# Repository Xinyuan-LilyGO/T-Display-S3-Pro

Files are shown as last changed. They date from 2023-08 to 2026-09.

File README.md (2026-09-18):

<div align="center" markdown="1">
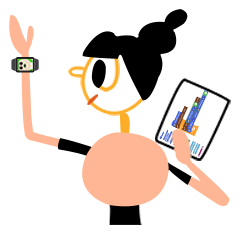
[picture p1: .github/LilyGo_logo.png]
LilyGo logo
  
</div>

<h1 align = "center">🌟 T-Display-S3-Pro 🌟</h1>



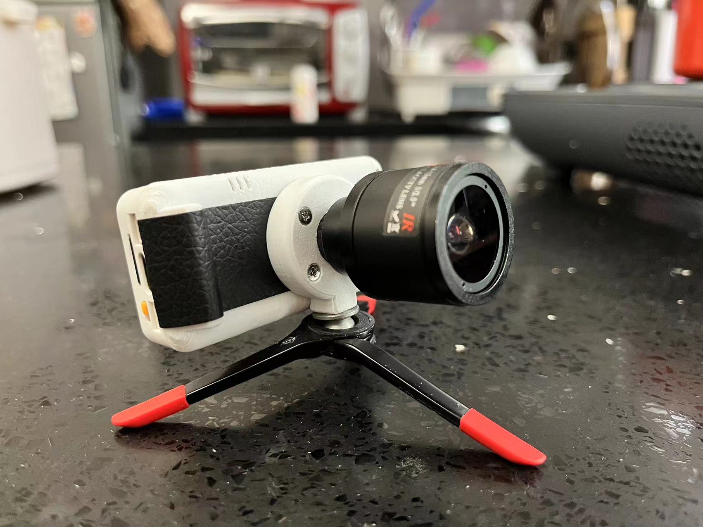
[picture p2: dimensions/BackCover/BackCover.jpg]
BackCover


---

## 📖 Table of Contents

- [📖 Table of Contents](#-table-of-contents)
- [📋 Product](#-product)
- [🚀 Quick Start](#-quick-start)
  - [PlatformIO Quick Start (Recommended)](#platformio-quick-start-recommended)
  - [Arduino IDE Quick Start](#arduino-ide-quick-start)
- [💾 Flash Factory Firmware](#-flash-factory-firmware)
- [🔧 Hardware Description](#-hardware-description)
  - [📍 Pins Map](#-pins-map)
  - [✨ Display Features](#-display-features)
  - [🧑🏼‍🔧 I2C Devices Address](#-i2c-devices-address)
  - [⚡ Electrical Parameters](#-electrical-parameters)
  - [💡 LED](#-led)
  - [🔌 QWIIC Connector](#-qwiic-connector)
  - [⏺︎ Button](#︎-button)
  - [📴 Switch](#-switch)
- [📚 Examples](#-examples)
  - [ESP32 Basic Examples](#esp32-basic-examples)
- [📄 Datasheet](#-datasheet)
- [📐 Case \& Dimensions](#-case--dimensions)
- [❓ FAQ](#-faq)
  - [1. Upload port not found?](#1-upload-port-not-found)
  - [2. Manual upload didn't work?](#2-manual-upload-didnt-work)
  - [3. OTG external power not working?](#3-otg-external-power-not-working)
  - [4. What does the physical switch do?](#4-what-does-the-physical-switch-do)
  - [5. LED flashing when battery not connected?](#5-led-flashing-when-battery-not-connected)
  - [6. Device suddenly shuts down?](#6-device-suddenly-shuts-down)
- [📦 Dependencies](#-dependencies)

---

## 📋 Product

| Product (PinMap) | SOC | Flash | PSRAM | Resolution | LTR-553ALS |
| --- | --- | ----- | --- | --- | --- |
| [T-Display-S3-Pro][1] | ESP32-S3R8 | 16MB  | 8MB(OPI) | 222x480 | ✅ |
| [T-Display-S3-Pro External][1]  | ESP32-S3R8 | 16MB  | 8MB(OPI) | 222x480 | X |
| [T-Display-S3-Pro-MVSRBoard][1] | - | - | - | - | |
| [T-Display-S3-Pro-MVSRLora][1]  | - | - | - | - | |

[1]: https://www.lilygo.cc/products/t-display-s3-pro
[2]: https://lilygo.cc/products/t-display-s3-pro-external

> **Note:**  The T-Display-S3-Pro supports multiple camera models, depending on the model purchased.
> The LTR-553ALS ambient light sensor is included only on the T-Display-S3-Pro; the T-Display-S3-Pro External does not feature this sensor.
>

---

## 🚀 Quick Start

### PlatformIO Quick Start (Recommended)

1. Install [Visual Studio Code](https://code.visualstudio.com/) and [Python](https://www.python.org/)
2. Search for the `PlatformIO` plugin in Visual Studio Code extension marketplace and install it
3. Restart Visual Studio Code after installation
4. Open `File` → `Open Folder` → select the `T-Display-S3-Pro` directory
5. Wait for third-party library dependencies to install automatically
6. Open `platformio.ini` and uncomment the desired `default_envs = xxxx` line (only one should be active)
7. Click the (✔) icon in the bottom-left corner to compile
8. Connect the board via USB, click (→) to upload firmware
9. Click the (plug symbol) to monitor serial output
10. If upload fails or the USB device keeps flashing, refer to the **FAQ** section below

### Arduino IDE Quick Start

> **Note:** PlatformIO is recommended for a smoother development experience.

1. Install [Arduino IDE](https://www.arduino.cc/en/software)
2. Add the ESP32 board URL in Arduino Preferences → `Additional boards manager URLs`:
   ```
   https://raw.githubusercontent.com/espressif/arduino-esp32/gh-pages/package_esp32_index.json
   ```
   > **Important:** Use Arduino ESP32 core version **2.0.14** or lower. Versions above 2.0.14 may have compatibility issues with TFT_eSPI. See [TFT_eSPI Issue #3329](https://github.com/Bodmer/TFT_eSPI/issues/3329)

3. Copy all folders from the [lib folder](./lib/) to your Arduino libraries directory (e.g., `C:\Users\YourName\Documents\Arduino\libraries`)
4. Configure the board settings as follows:

   | Setting          | Value                               |
   | ---------------- | ----------------------------------- |
   | Board            | **ESP32S3 Dev Module**              |
   | Port             | Your port                           |
   | USB CDC On Boot  | Enable                              |
   | CPU Frequency    | 240MHz (WiFi)                       |
   | Flash Mode       | QIO 80MHz                           |
   | Flash Size       | **16MB (128Mb)**                    |
   | Partition Scheme | **16M Flash (3MB APP/9.9MB FATFS)** |
   | PSRAM            | **QSPI PSRAM**                      |
   | Upload Speed     | 921600                              |

5. Open `T-Display-S3-Pro` → `examples` → select an example → open the `.ino` file
6. Select the correct Port and click Upload

> **Troubleshooting:** If upload fails or the USB device keeps flashing, refer to the **FAQ** section below.

---

## 💾 Flash Factory Firmware

If you need to restore the factory firmware or flash the UnitTest firmware for hardware testing, please refer to the [Firmware Flashing Guide](./firmware/README.MD).

---

## 🔧 Hardware Description

### 📍 Pins Map

| Name | GPIO | Note |
| --- | --- | --- |
| SDA | 5 | |
| SCL | 6 | |
| SPI MISO | 8 | |
| SPI MOSI | 17 | |
| SPI SCLK | 18 | |
| DISPLAY CS | 39 | |
| DISPLAY MISO/MOSI/SCLK | 8/17/18 | Share SPI Bus |
| BACKLIGHT PIN | 48 | 16-level dimming |
| SD CS | 14 | |
| SD MISO/MOSI/SCLK | 8/17/18 | Share SPI Bus |
| TOUCH RST | 13 | |
| TOUCH SDA/SCL | 5/6 | Share I2C Bus |
| BUTTON 1 (BOOT) | 0 | User button, also used for download mode |
| BUTTON 2 | 12 | User button |
| BUTTON 3 | 16 | User button |
| On board LED (Green) | 38 | |
| CAMERA RST | - | NC |
| CAMERA SDA/SCL | 5/6 | Share I2C Bus |
| CAMERA VSYNC | 7 | |
| CAMERA POWER DOWN | 46 | |
| CAMERA HREF | 15 | |
| CAMERA XCLK | 4 | |
| CAMERA PCLK | 2 | |
| CAMERA Y2-Y9 | 45,41,40,42,1,3,10,4 | |
| CAMERA LED | 38 | Share Onboard LED |
| CAMERA Default frequency | 20MHz | |

> **Note:** V1.0 uses PWM for backlight adjustment, while V1.1 uses constant current drive. See [AdjustBacklight example](./examples/AdjustBacklight/AdjustBacklight.ino) for details.

### ✨ Display Features

| Feature | Value |
| --- | --- |
| Resolution | 480 × 222 |
| Display Size | 2.33 Inch |
| Luminance | 450 cd/m² |
| Driver IC | ST7796U (SPI) |
| Contrast Ratio | 1000:1 |
| Color Gamut | 70% |
| PPI | 221 |
| Display Colors | 262K |
| View Direction | All (IPS) |
| Operating Temperature | -20 ~ 70°C |

### 🧑🏼‍🔧 I2C Devices Address

| Device | 7-Bit Address | Shared Bus |
| --- | --- | --- |
| [PowerManage SY6970][2] | 0x6A | ✅ |
| [Optical Sensor LTR-553ALS][3]  | 0x23 | ✅ |
| Capacitive Touchscreen CST226SE | 0x5A | ✅ |

[2]: https://www.visvie.com/static/upload/file/20220916/1663318546578220.pdf
[3]: https://optoelectronics.liteon.com/upload/download/DS86-2014-0007/LTR-553ALS-01_DS_V1.pdf

### ⚡ Electrical Parameters

| Feature | Details |
| --- | --- |
| 🔗 USB-C Input Voltage  | 3.9V - 6V |
| 🔗 USB-C Output Voltage | 4.55 - 5.55V |
| ⚡ USB-C Output Current | 0.5 - 1A |
| ⚡ Charge Current | 0 - 5056mA (Programmable) |
| 🔋 Battery Voltage | 3840 ~ 4608mV (Programmable) |
| 🔋 Battery Capacity | 3800mV / 470mAh |
| 🔋 Battery Connector | [ACHL Connector 1.2mm][4] |
| 🔋 Charge Temperature | 0 ~ 60°C |

[4]: https://www.jst.com/zh/products/crimp-style-connectors-wire-to-board-type/achl-connector/

> [!IMPORTANT]
> - ⚠️ Recommended charging current: **< 200mA**
> - ⚠️ Charging current should not exceed half of battery capacity
> - The T-Display-S3-Pro uses the SY6970 power path switching chip. To maintain stable power when battery is disconnected, charging must be disabled. See [PMU_Example](https://github.com/Xinyuan-LilyGO/T-Display-S3-Pro/blob/c267d7463609e1f6c62e74455ac5048c9ae93bc3/examples/PMU_Example/PMU_Example.ino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) for details.

### 💡 LED

| LED | GPIO | Note |
| --- | ---- | --- |
| Green LED | 38 | Shared with camera fill light on camera shield models |
| Red LED | - | Charger status indicator |

> **Note:** The red LED flashes when no battery is connected. Disable via `PMU.disableStatLed();` - see [FAQ](#faq).

### 🔌 QWIIC Connector

| Connector | GPIO | Description |
| --- | --- | --- |
| LEFT | 44, 43, 3V3, GND | UART / I2C / GPIO |
| RIGHT | SCL(6), SDA(5), 3V3, GND | I2C only |

> **Note:** Screen should be facing you to determine direction.

### ⏺︎ Button

| LED | GPIO | Note |
| --- | --- | --- |
| LEFT TOP | RESET | Reset Device |
| LEFT BOTTOM  | BOOT (GPIO0) | User button, also used for download mode |
| RIGHT TOP | 12 | User button |
| RIGHT BOTTOM | 16 | User button |

> **Note:** Screen should be facing you to determine direction.

### 📴 Switch

* The power switch is only effective when the battery is connected; disconnect the battery from the motherboard.

---

## 📚 Examples

```txt
T-Display-S3-Pro examples
├── examples/Arduino_GFX_HelloWorld      # Arduino_GFX getting started
├── examples/Arduino_GFX_LvglBenchmark   # Arduino_GFX + LVGL benchmark
├── examples/Arduino_GFX_PDQgraphicstest  # Arduino_GFX graphics test
├── examples/CameraShield                 # Camera example
├── examples/CapacitiveTouch              # Capacitive touch example
├── examples/LTR553ALS_Sensor             # Light & proximity sensor
├── examples/TFT_eSPI_Simple             # TFT_eSPI example
├── examples/USB_HID_Example              # USB Host HID & OTG
├── examples/UnitTest                     # Hardware unit testing
├── examples/PMU_Example                  # Power management & battery info
├── examples/AdjustBacklight              # Backlight adjustment
├── examples/Cellphone                    # Camera & photo album (SD required)
└── examples/factory                     # Factory testing
```

> [!CAUTION]
> When using `examples/Cellphone`, do not block the top of the "S3-Pro" screen area. Blocking this area will cause the screen to sleep.

Expansion board examples:

- [T-Display-S3-Pro-MVSRBoard](https://github.com/Xinyuan-LilyGO/T-Display-S3-Pro-MVSRBoard)
- [T-Display-S3-Pro-MVSRLora](https://github.com/Xinyuan-LilyGO/T-Display-S3-Pro-MVSRLora)

### ESP32 Basic Examples

- [BLE Examples](https://github.com/espressif/arduino-esp32/tree/master/libraries/BLE)
- [WiFi Examples](https://github.com/espressif/arduino-esp32/tree/master/libraries/WiFi)
- [SPIFFS Examples](https://github.com/espressif/arduino-esp32/tree/master/libraries/SPIFFS)
- [FFat Examples](https://github.com/espressif/arduino-esp32/tree/master/libraries/FFat)
- More examples available at [arduino-esp32-libraries](https://github.com/espressif/arduino-esp32/tree/master/libraries)

---

## 📄 Datasheet

- [Camera-Shield](./schematic/Camer-Shield.pdf)
- [T-Display-S3-Pro](./schematic/T-Display-Pro.pdf)
- [T-BHI260](./schematic/T-BHI260_V1.1.pdf)
- [T-Display-S3-Pro-MVSRBoard_V1.0_20240913](./schematic/T-Display-S3-Pro-MVSRBoard_V1.0_20240913.pdf)
- [T-Display-S3-Pro-MVSRBoard_V1.0_20241109](./schematic/T-Display-S3-Pro-MVSRBoard_V1.0_20241109.pdf)

## 📐 Case & Dimensions

- 🔓 Cool back cover design by @moononournation - [Design files](./dimensions/BackCover/)
- [T-Display-Pro PCB](./dimensions/T-Display-Pro-PCB.DWG)
- [T-Display-Pro-Vice-Shield](./dimensions/T-Display-Pro-Vice-Shield.dxf)
- [T-Display-Pro-Vice-Shield Gerber](./dimensions/T-Display-Pro-Vice-Shield%20Gerber%2023-11-23.zip)
- [T-BHI260.kicad_mod](./schematic/kicad_sensor.pretty/T-BHI260.kicad_mod)
- [T-CIM29048.kicad_mod](./schematic/kicad_sensor.pretty/T-CIM29048.kicad_mod)

---

## ❓ FAQ

### 1. Upload port not found?

The board uses USB as the JTAG upload port. Ensure `USB_CDC_ON_BOOT` is enabled.

If the port does not appear or USB is used for other functions, enter upload mode manually:

1. Connect the board via USB cable
2. Press and hold the **BOOT** button
3. While holding BOOT, press **RST**
4. Release RST
5. Release BOOT
6. Retry upload

### 2. Manual upload didn't work?

Try burning the [firmware file](./firmware/README.MD) to verify hardware functionality.

### 3. OTG external power not working?

Enable [PMU OTG](https://github.com/Xinyuan-LilyGO/T-Display-S3-Pro/blob/d7f15b379da2b6f711998315401c02a740a8bfa8/examples/CameraShield/CameraShield.ino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). When USB input is connected and OTG is set to output, the battery will not charge.

### 4. What does the physical switch do?

Setting the switch to **OFF** completely disconnects the battery from the mainboard. Set to **ON** for charging.

### 5. LED flashing when battery not connected?

Use `PMU.disableStatLed();` to disable the indicator. Note this also disables the charging status indicator. To re-enable, call `PMU.enableStatLed();`

### 6. Device suddenly shuts down?

Sudden shutdown only occurs when battery is not connected. Solution: disable SY6970 charging. See [PMU_Example](https://github.com/Xinyuan-LilyGO/T-Display-S3-Pro/blob/c267d7463609e1f6c62e74455ac5048c9ae93bc3/examples/PMU_Example/PMU_Example.ino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).

---

## 📦 Dependencies

| Library | Repository |
| --- | --- |
| XPowersLib | [GitHub](https://github.com/lewisxhe/XPowersLib) |
| SensorLib | [GitHub](https://github.com/lewisxhe/SensorLib) |
| lvgl | [GitHub](https://github.com/lvgl/lvgl) (v8.3.1) |
| TFT_eSPI | [GitHub](https://github.com/Bodmer/TFT_eSPI) |
| TouchLib | [GitHub](https://github.com/mmMicky/TouchLib) |
| Arduino_GFX | [GitHub](https://github.com/moononournation/Arduino_GFX) |
| MPU9250 | [GitHub](https://github.com/hideakitai/MPU9250) |
| MPU6050 | [GitHub](https://github.com/electroniccats/mpu6050) |
| ESP32_USB_Stream | [GitHub](https://github.com/esp-arduino-libs/ESP32_USB_Stream) (v0.0.1) |
| ESP32-audioI2S | [GitHub](https://github.com/schreibfaul1/ESP32-audioI2S) (v3.0.8) |
| JPEGDEC | [GitHub](https://github.com/bitbank2/JPEGDEC) (v1.2.8) |

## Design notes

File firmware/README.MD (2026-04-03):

<div align="center" markdown="1">
  LilyGo logo
</div>

<h1 align = "center">🌟 How to Flash Firmware 🌟</h1>

## Table of Contents

- [Table of Contents](#table-of-contents)
- [Firmware](#firmware)
- [Enter Download Mode](#enter-download-mode)
- [Flash Methods](#flash-methods)
  - [ESP-Launchpad Online](#esp-launchpad-online)
  - [Use ESP Download Tool](#use-esp-download-tool)
  - [Use Web Flasher](#use-web-flasher)
  - [Use Command Line](#use-command-line)
- [Verify Flashing Success](#verify-flashing-success)
  - [Check Boot Log](#check-boot-log)

## Firmware

The difference between V1.0 and V1.1 is that the backlight driver is different. If the wrong firmware is flashed, the backlight may not work correctly.

| Firmware | Description |
| --- | --- |
| Factory_1.x.bin | Default factory-installed desktop firmware |
| UnitTest_V1.x_Release.bin | Firmware for testing hardware, outputting debugging information to Qwiic UART |
| UnitTest_V1.x_Debug.bin | Firmware for testing hardware, output debugging information to USB CDC |
| UnitTest_V1.x_DiscChg_Release.bin | Firmware for testing hardware, disable charge function, outputting debugging information to Qwiic UART |
| UnitTest_V1.x_DiscChg_Debug.bin | Firmware for testing hardware, disable charge function, output debugging information to USB CDC |

## Enter Download Mode

> [!CAUTION]
> Before flashing, you need to know how to put your device into download mode.

1. Connect the board via USB cable
2. Press and hold the **BOOT** button
3. While holding BOOT, press **RST**
4. Release RST
5. Release BOOT
6. Retry upload
7. If the USB port is recognized, the device enters download mode.

## Flash Methods

### ESP-Launchpad Online

- [Esp-launchpad](https://espressif.github.io/esp-launchpad/)

ESP-Launchpad

* Note that after flashing is completed, you need to press RST to reset.

### Use ESP Download Tool

- Download [Flash_download_tool](https://dl.espressif.com/public/flash_download_tool.zip)

web_flasher

* Note that after flashing is completed, you need to press RST to reset.

### Use Web Flasher

- [ESP Web Flasher Online](https://espressif.github.io/esptool-js/)

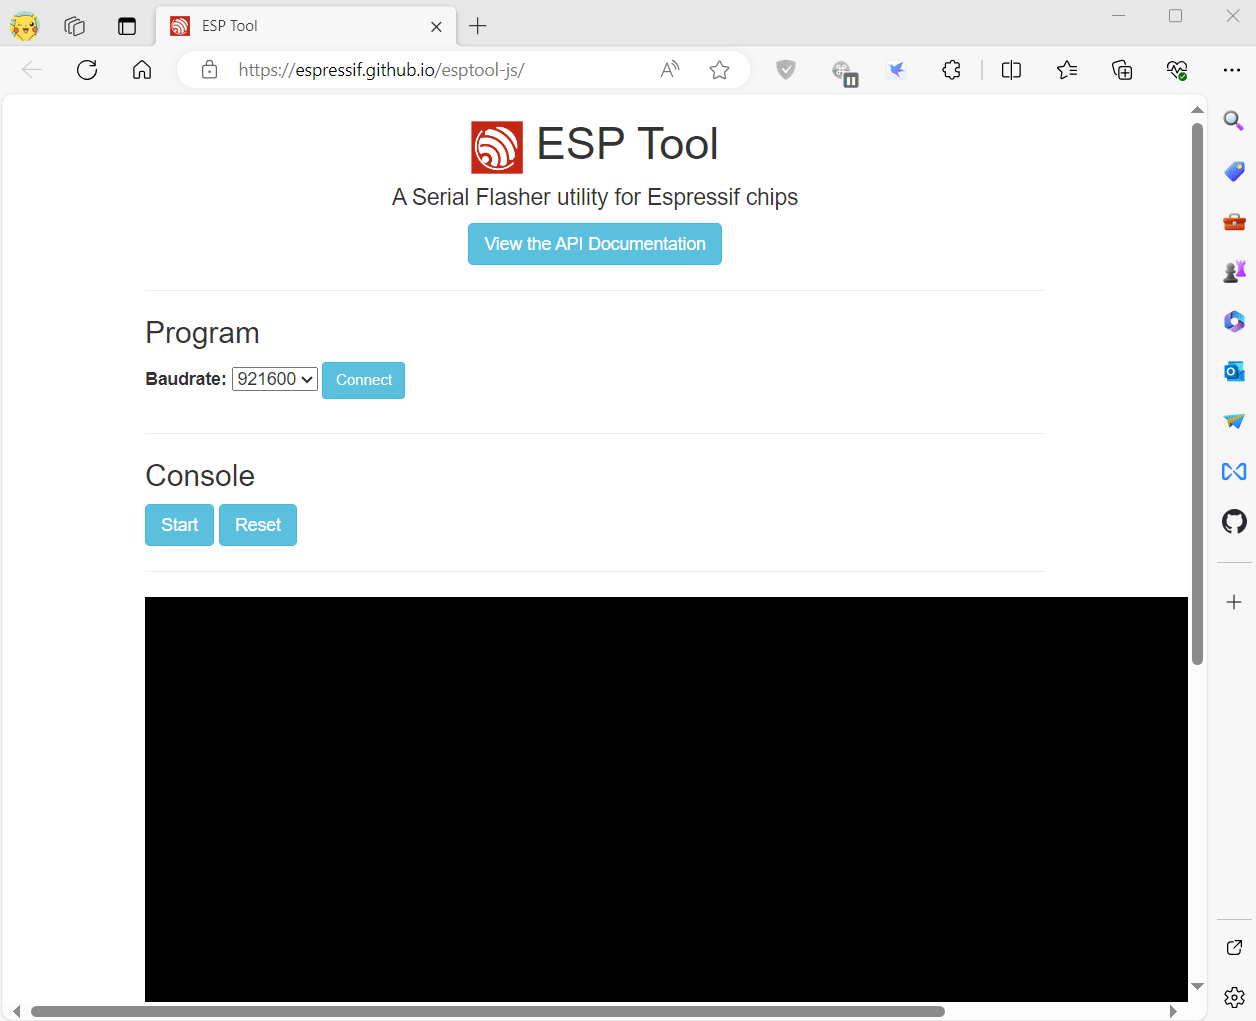
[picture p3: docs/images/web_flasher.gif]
web_flasher


* Note that after flashing is completed, you need to press RST to reset.

### Use Command Line

If prompted to install Developer Tools, do so.

```bash
python3 -m pip install --upgrade pip
python3 -m pip install esptool
```

To launch esptool.py, run:

```bash
python3 -m esptool
```

For ESP32-S3, use the following command to flash:

```bash
esptool --chip esp32s3  --baud 921600 --before default_reset --after hard_reset write_flash -z --flash_mode dio --flash_freq 80m 0x0 firmware.bin
```

## Verify Flashing Success

### Check Boot Log

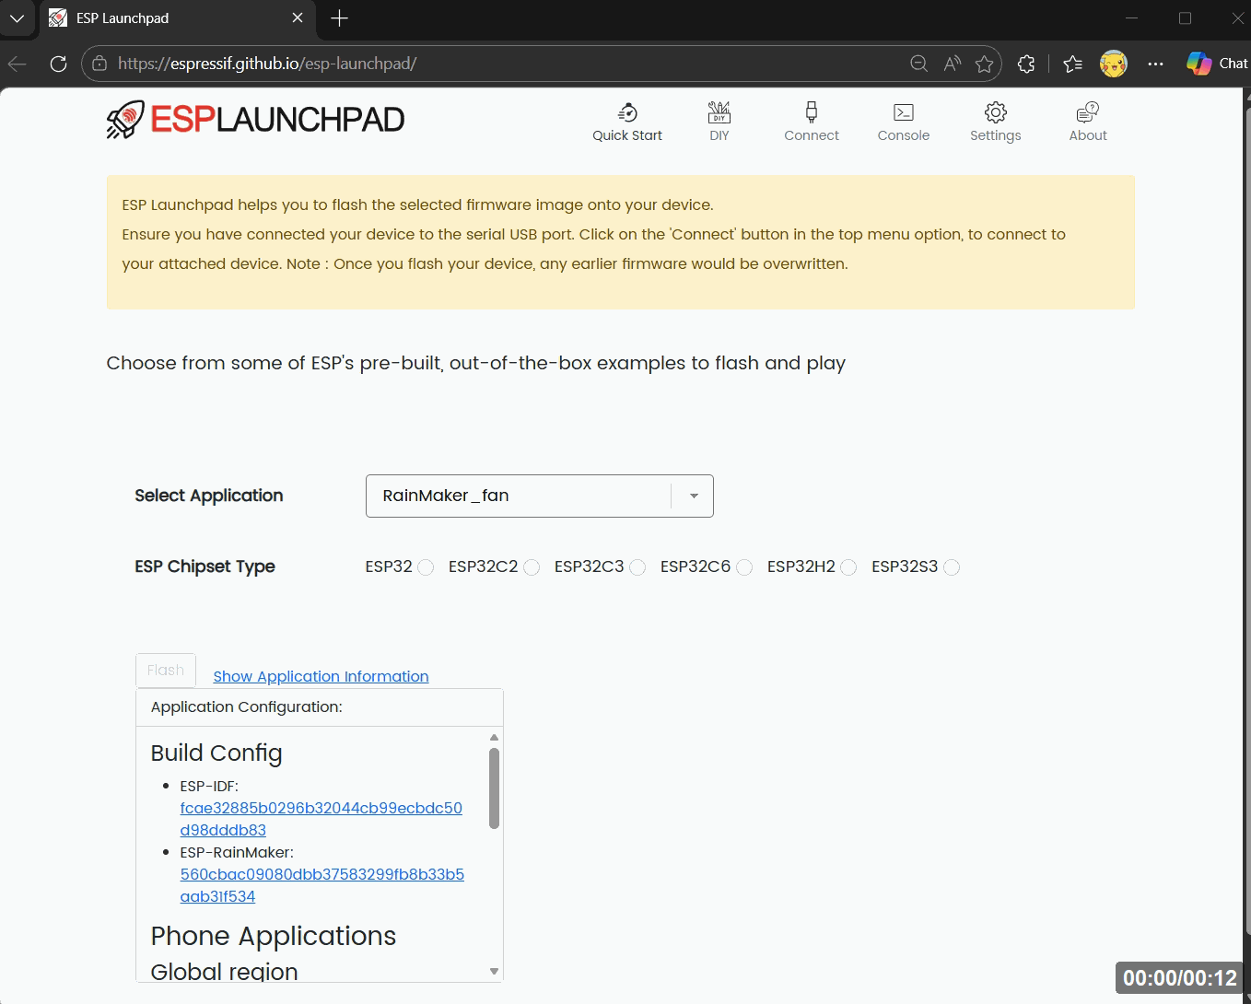
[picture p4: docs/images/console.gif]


* If you can see the device's boot log printed by resetting it serially, and the USB port is recognized, then it has booted normally.
* If the USB port is not recognized and is flashing after uploading, it may be due to an incorrect firmware address. Generally, the write address for LilyGo firmware is 0x00.

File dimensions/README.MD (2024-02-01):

# T-Display-Pro-Vice-Shield

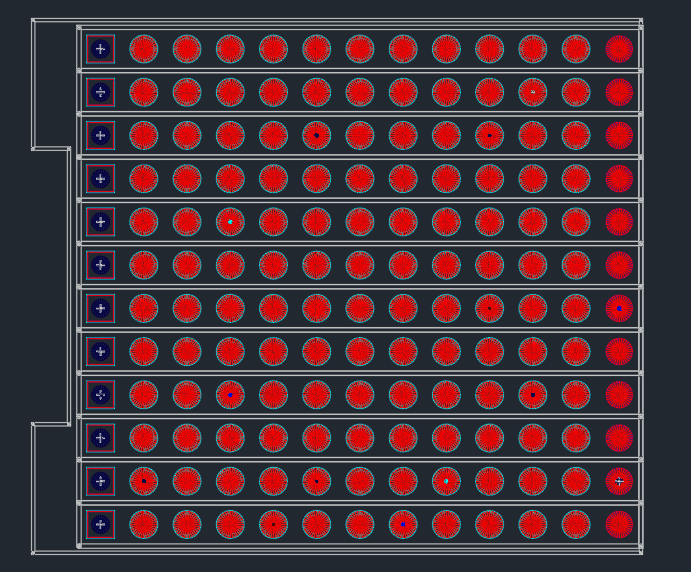
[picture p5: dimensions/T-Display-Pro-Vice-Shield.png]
T-Display-Pro-Vice-Shield


# BackCover 

**Contributed by @moononournation**
 


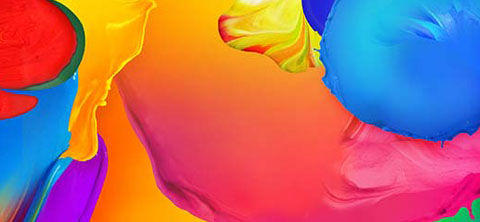
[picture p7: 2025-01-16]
examples/TJpg_Decoder/480x222.jpg

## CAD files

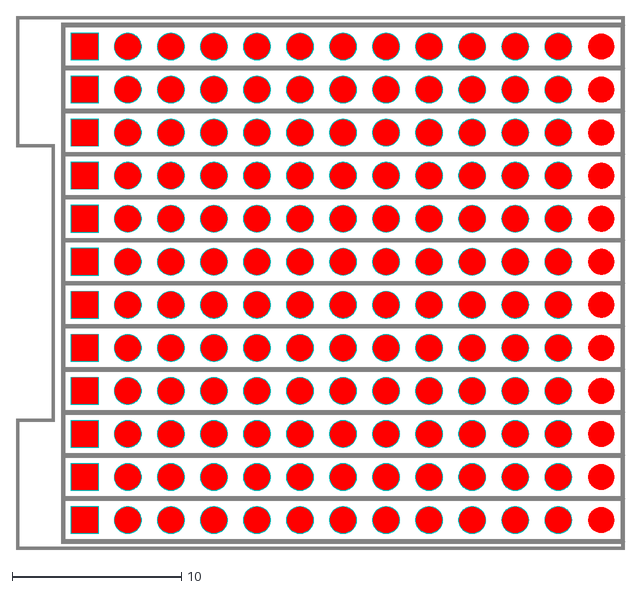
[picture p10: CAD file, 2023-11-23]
dimensions/T-Display-Pro-Vice-Shield.dxf
35.9 x 31.5

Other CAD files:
dimensions/T-Display-Pro-PCB.DWG
dimensions/BackCover/K231-camera-back v6.f3d
dimensions/BackCover/K231-lens-mount v3.f3d

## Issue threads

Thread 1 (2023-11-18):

lib/Arduino_GFX directory is empty so the Arduino_GFX* examples fail to build

esp32beans, 2023-11-18:
Installing "GFX Library for Arduino" by "Moon On Our Nation" version 1.4.0 (latest) using the IDE Library manager fixes the problem. All the Arduino_GFX_* examples work fine now.

lewisxhe, 2023-12-29:
Fixed

Closed 2023-12-29.

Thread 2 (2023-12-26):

Battery information

stutteringp0et, 2023-12-26:
Having been burned by one of your products before, where a replacement battery cannot be purchased - I'd like some information on the battery included with this device.  Specifications so I can determine if a replacement can be sourced when the included battery fails.

lewisxhe, 2023-12-29:
I will add it later, I need to consult

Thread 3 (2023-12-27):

Black Screen

Mcfly46, 2023-12-27:
Hello,
I Have black screen with my device.
I flashed with the factory bin  but no screen. So hardware is broken ?
Thank you.

lewisxhe, 2023-12-29:
Did you follow the instructions?
https://github.com/Xinyuan-LilyGO/T-Display-S3-Pro/tree/master/firmware

jalakoo, 2024-07-11:
I have a similar issue. Regardless of sample app used, after uploading I end up with a blank, black screen.

Using a Mac, so the flash download tool isn't available. Have yet to find an alternate means of flashing the factory.bin to the board.

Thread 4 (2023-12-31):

Touch not working reliable

pixelwave, 2023-12-31:
I have the issue that the touch screen is not working reliable on my T-Display-S3-Pro. The problem is with the factory code as well as my custom code using Arduino GFX + LVGL. When using the "capacity touch" sample code it seems to detect all inputs so it does not really seem like the device itself is broken? I also have a second unit - same behaviour?

https://github.com/Xinyuan-LilyGO/T-Display-S3-Pro/assets/19491804/4728e317-8e50-4639-a78a-a0311a4c3041

https://github.com/Xinyuan-LilyGO/T-Display-S3-Pro/assets/19491804/d52b48f9-dbf8-43fa-9f5b-b6b743c385fd

lewisxhe, 2023-12-31:
First confirm whether the touch is normal, you can write https://github.com/Xinyuan-LilyGO/T-Display-S3-Pro/tree/master/examples/CapacitiveTouch to test.

pixelwave, 2023-12-31:
> First confirm whether the touch is normal, you can write https://github.com/Xinyuan-LilyGO/T-Display-S3-Pro/tree/master/examples/CapacitiveTouch to test.

Did you read my post? That is what I already confirmed „.. when using the "capacity touch" sample code it seems to detect all inputs so it does not really seem like the device itself is broken“.

pixelwave, 2023-12-31:
Still troubleshooting … the issue seems to get worse when using battery instead of usb power?

lewisxhe, 2023-12-31:
When you apply it in your project, have you printed the touch output coordinates and are they normal? Or do you display it on the screen and observe whether the coordinates are the same as the actual touch position?

pixelwave, 2024-01-01:
So I can confirm it has something to do with battery vs usb powered mode.

You can try my sample code yourself (https://github.com/pixelwave/t-display-s3-pro) with the following test setups:

1) Power Switch "OFF", connected and powered from USB port (PC/Laptop)
2) Power Switch "ON" battery powered only

In scenario 1) the touch inputs work reliably and 99% of the time. In Scenario 2) the touch is a hit and miss. Sometimes the buttons work sometimes not.

So in summary I assume a general hardware issue with the board design. I hope this can be resolved in an updated version (I have V1.1) because otherwise the product is quite awesome! But with that flaw currently unusable im battery mode.

Contacting support to find a solution ..

ShallowGreen123, 2024-01-02:
Please tell me how many S3-Pro you bought in total, you can contact the after-sales service to return or replace the goods.

pixelwave, 2024-01-02:
I bought 2 in total already contacted sales (sales@lilygo.cc) and they forwarded it to the orders (orders@lilygo.cc) team. Currently waiting for their feedback. I noticed you are using a different unit? Is it maybe a preproduction or newer unit? Has there been any updates since V1.1? Because both my units show the same behaviour I tend to believe it is more a general hardware design issue?

See below my production (V1.1) device with and without cable:

https://github.com/Xinyuan-LilyGO/T-Display-S3-Pro/assets/19491804/058bc7e9-1d75-4273-9e98-23b69ad9c587

https://github.com/Xinyuan-LilyGO/T-Display-S3-Pro/assets/19491804/4569dcfc-1853-47ad-8aff-7bc7a3949baa

lewisxhe, 2024-01-02:
I know what your problem is. Please change it to the following:
`
build_flags=
        ; -DARDUINO_USB_CDC_ON_BOOT=1
        -UARDUINO_USB_CDC_ON_BOOT
`

If Cdc is turned on, the serial port will block the program from running.

pixelwave, 2024-01-02:
The arguments are as written in the official lilygo sample code.

But I compiled it with the variables like you suggested:
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

No change same behaviour. When in "battery mode" touch screen does NOT work reliably.

lewisxhe, 2024-01-03:
Please note that
`
; -DARDUINO_USB_CDC_ON_BOOT=1
`
has been commented out and
`
 -UARDUINO_USB_CDC_ON_BOOT
`
is enabled

pixelwave, 2024-01-03:
Compiled now like this:

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

Still unchanged behaviour. USB powered = all fine. Battery powered = touch very janky.

lewisxhe, 2024-01-03:
If you can try to enter the binary file I provided, and test whether it is caused by environmental reasons.

The writing method can follow  [here](https://github.com/Xinyuan-LilyGO/LilyGo-Document/blob/master/MacFlashBin.md)

[t-display-s3-pro_0103.zip](https://github.com/Xinyuan-LilyGO/T-Display-S3-Pro/files/13816595/t-display-s3-pro_0103.zip)

pixelwave, 2024-01-03:
Flashed once with esptool and once with thonny. Same faulty behaviour.

pixelwave, 2024-01-03:
Flashing worked both times. I just wanted to try with different tools. Also both times completely erased flash.

The touch problem is still there.

lewisxhe, 2024-01-03:
I have received a message from customer service. I am very curious about what the problem is. Customer service will communicate with you next. I hope to send back these two boards. I want to find out the reason.

pixelwave, 2024-01-03:
Yes me too! Would love to ultimately fix the problem and have working boards. Because the product and paper is great. So I am going to contact with customer support next to send the boards back? I will leave the code on there for you to check ...

pixelwave, 2024-01-08:
... support is not answering anymore? I asked how to return the product. Can you help or contact them?

lewisxhe, 2024-01-08:
Haven't you already contacted customer service?

lewisxhe, 2024-01-08:
Tomorrow I will ask how to deal with it, and I will reply to you here after I get the answer.

pixelwave, 2024-01-08:
Thanks a lot!

lewisxhe, 2024-01-10:
> Thanks a lot!

Did customer service contact you?

pixelwave, 2024-01-10:
Did yesterday - thanks for pinging. But still waiting for their solution on how to ship back the products.

samarkh, 2024-02-25:
My unit also has the same issue, fine on USB power, but bad when self-powered.

pixelwave, 2024-02-25:
After all testing I really think it is a hardware based issue. Maybe just for this specific revision (mine was V1.1). @lewisxhe BTW I am still waiting for the shipping cost refund until I can return the two units for you to test ...

lewisxhe, 2024-03-05:
@pixelwave Hi, have you not arranged how to ship it back after the sale? It's a little weird that both of them have problems. If I can ship them back, I will check what caused the problem.

czm8, 2024-03-16:
I'm wondering if anyone knows if there is a solution for this. I recently came across the same issue - When I have the T-Display S3 Pro connected to my computer with a USB cable the touch screen reacts quickly and perfectly. However, when I disconnect the USB cable from the T-Display S3 Pro the touch because much less reliable and often doesn't sense my finger touching the screen. I have it set up so that it displays the x and y coordinates on the screen so I can see if it sees where I touched the screen and there I can see that the numbers do not change.

I have also recreated the problem I was seeing before - this time using the "CapacitiveTouch" example provided by LilyGo on their GITHUB page meaning I can rule out anyting in my code as being a problem. [https://github.com/Xinyuan-LilyGO/T-Display-S3-Pro/tree/master/examples/CapacitiveTouch](https://github.com/Xinyuan-LilyGO/T-Display-S3-Pro/tree/master/examples/CapacitiveTouch)

To summarize, the problem is a follows, when the unit is powered from the USB port, it recognizes all touches on the screen without any problems. When the USB power is removed and the unit is powered by the internal battery it sometimes works and sometimes doesn't recognize the touches on the screen. This makes the T Display S3 Pro unusable for me as a battery powered, portable device.

I have sent LilyGo an email about this issue but I still have not heard back from them. Oh and my unit is version 1.1

pixelwave, 2024-03-17:
> @pixelwave Hi, have you not arranged how to ship it back after the sale? It's a little weird that both of them have problems. If I can ship them back, I will check what caused the problem.

I wrote customer service now one last time. The faulty products are packed and ready to ship batteries removed and all as advised. But they still did not refund the return shipping cost. In fact it took so long DHL now raised fees for shipping. -.-

If you guys are still interested in receiving the faulty products I told them they have until March 22nd to respond - otherwise I will destroy them and close this case.

**But seeing now more and more cases popping up - again I believe it is probably a hardware issue of the entire batch / revision. So you should be able to also recreate this error if you have a hardware version V1.1 laying around ...**

pixelwave, 2024-04-09:
@lewisxhe

Did the boards arrive by now? I saw some people have the same issue with the T-Display-S3-Pro. Could you maybe verify this with a hardware revision (V1.1) if you have units available locally?

lewisxhe, 2024-04-09:
I haven't received the package yet, it should still be on its way. I will test it as soon as I receive it.
All factory tests are conducted using batteries for power supply, and no such situation has been found so far

pixelwave, 2024-04-29:
Hi @lewisxhe, any updates so far?

lewisxhe, 2024-04-29:
Just inquired and it has arrived, I will test it as soon as I get it

lewisxhe, 2024-04-30:
@pixelwave I have tested the two boards you sent back. One of them is labeled with a defective device. I tested it and the touch was very insensitive when powered by battery. After testing, it became normal after replacing the screen, so I suspect it is. The sensitivity of the capacitive touch screen decreases when powered by battery, but works normally when powered by USB. I have reported the problem to the supplier.

Judging from the current tests, it is the touch sensitivity of the screen that causes the touch to be insensitive. I have added a touch screen test to the factory test steps. This should be avoided in the future. Thank you again for your feedback.

lewisxhe, 2024-04-30:
oh! By the way, another device without a label is powered by a battery. My test here is normal and no problem is found.

pixelwave, 2024-04-30:
@lewisxhe Thanks for the feedback. As I also expected seemed to be a hardware issue. I my case both products I ordered showed the same faulty behavior. Maybe it was a bad batch / slipped through quality control.

Would be nice to receive an updated (V1.2) or quality controlled version. I still like the board / form-factor combination for a lot of use-cases. But the touch needs to work reliably every time when running on battery ...

pixelwave, 2024-06-05:
@lewisxhe

"The sensitivity of the capacitive touch screen decreases when powered by battery, but works normally when powered by USB. I have reported the problem to the supplier."

Is there a new hardware revision out that solves this issue? I am still very interested in the product.

lewisxhe, 2024-06-05:
You just need to place a new order. All our products are tested before leaving the factory.

ripplebiz, 2024-08-15:
I am experiencing the same touch problems when powered by battery.
My unit was only purchased recently, about beginning of Aug. So, is this faulty touch hardware still an issue?

pixelwave, 2024-08-15:
> I am experiencing the same touch problems when powered by battery. My unit was only purchased recently, about beginning of Aug. So, is this faulty touch hardware still an issue?

What is your hardware revision (if I remember correctly it should be printed on the PCB if you remove the battery)? Mine was "V1.1".

ripplebiz, 2024-08-15:
I have the 'expansion' version, and doesn't have a battery. Can't see the PCB, so not sure what the version is.

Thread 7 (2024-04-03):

Compilation error: 'lv_font_montserrat_16' was not declared in this scope

ortiztx, 2024-04-03:
Hi, I have just received my new T-Display-S3 and after uploading a couple of examples, I wanted to return to the initial factory firmware.
But I always receive the same issue:

**Compilation error: 'lv_font_montserrat_16' was not declared in this scope**

It is about this font I don't know how to fixed, it is just in the ui.cpp file and in no other place.

Please, can you help on this?

Thank you,

Tomas

Closed 2024-04-06.

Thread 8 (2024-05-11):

SD init issue

spilz87, 2024-05-11:
Hello
I really like this device 👍

But I can not manage SD card :(

Can someone help me with a small code to init sd card ?

(I tried different way but it doesn’t seems to work or it impacts screen :( )

Thanks in advance

lewisxhe, 2024-05-17:
One SPI bus with multiple devices, see the example how to do it
https://github.com/Xinyuan-LilyGO/T-Display-S3-Pro/blob/master/examples/UnitTest/UnitTest.ino#L202

spilz87, 2024-05-17:
@lewisxhe thanks 😁

solution : using semaphore

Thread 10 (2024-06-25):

Serial prints are not working.

gahisee, 2024-06-25:
I'm using VS Code on Kubuntu and various examples all run fine.
Except no serial prints are showing in the monitor.
At one point, I did see error output from HTTPClient library but nothing
from the app I'm running.

lewisxhe, 2024-08-05:
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

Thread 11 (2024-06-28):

Stemma QT Pinout

everybodyfloats, 2024-06-28:
Can you provide the Stemma QT Pinout?

aleonnet, 2024-07-04:
Hi @lewisxhe

Can you please provide an example to use this Stemma QT/UART for connecting an AT6558 navigation chip/GPS?
Would something like this work?

#include <HardwareSerial.h>
static const uint32_t GPSBaud = 9600;
HardwareSerial GPSRaw(2);

void Setup() {
    GPSRaw.begin(GPSBaud);
...
}

void Loop(){
    if (GPSRaw.available()) {
        int ch = GPSRaw.read();
        uiRenderer.drawTextBox(mapSprite, String(ch), 10, 10, 4, TFT_WHITE);
    }
..
}

lewisxhe, 2024-07-04:
Refer to here, specify RX TX before initialization
https://github.com/Xinyuan-LilyGO/LilyGo-AMOLED-Series/blob/299a71b1f79d5f372edfa2c1e0336e0de47b8b87/examples/QWIIC_GPS_Shield/QWIIC_GPS_Shield.ino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

aponert, 2025-05-04:
> Can you provide the Stemma QT Pinout?

Because I stumbled on this. I think the schematic shows it very nicely:

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

Also the pinout is printed on the PCB.

So, with the device display side upwards and the stemma qt / qwiic ports pointing towards you, the pinout is:

Left port: U0RXD | U0TXD | 3v3 | GND
Right port: SCL | SDA | 3v3 | GND

While ESP32-S3 might be flexible assigning pins to alternative functions, I would not recommend to re-assign those pins. I have the strong feeling they are hardwired to the sensors and by reassigning you would loose light sensor, touch and power control.

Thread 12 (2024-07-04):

CameraControlBT-TDS3P - Not an issue.

thorsten-l, 2024-07-04:
i've written a camera controller for Canon digital cameras with Bluetooth connectivity, based on LILIGO T-Display S3 Pro.

https://github.com/thorsten-l/CameraControlBT-TDS3P

I hope you have the time to try it out, and give me a feedback if you like it nor not :-)

Ciao
Thorsten

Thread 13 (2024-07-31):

CST226SE_SLAVE_ADDRESS

RanHam335, 2024-07-31:
I'm attempting to get the device programmed in ESP-IDF and I can't find the value of CST226SE_SLAVE_ADDRESS. Let alone I can't find any documentation on CST226SE touch controller

lewisxhe, 2024-08-05:
The document is all in Chinese and hard to understand. Here is an example of idf

https://github.com/lewisxhe/SensorLib/blob/master/datasheet/%E6%B5%B7%E6%A0%8E%E5%88%9B%E8%A7%A6%E6%91%B8%E8%8A%AF%E7%89%87%E7%A7%BB%E6%A4%8D%E6%89%8B%E5%86%8C-v3.5-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

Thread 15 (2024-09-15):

wrong TFT_ESPI driver

smartelements, 2024-09-15:
I just got the new T-Display S3 Board and was not able to test with any example. The CPU restarts all the time. Only the BIN files worked. The TFT_ESPI driver definately is not the correct version. Please help

lewisxhe, 2024-09-18:
The highest version of TFT_eSPI currently only supports version 2.0.14

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

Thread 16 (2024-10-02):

error compilation

lopsterman, 2024-10-02:
C:\Users\Professional\Desktop\T-Display-S3-Pro-master\examples\factory\sd_card.cpp: In function 'bool sd_card_bmp_lvgl(const char*, uint32_t, uint32_t, lv_obj_t*)':
C:\Users\Professional\Desktop\T-Display-S3-Pro-master\examples\factory\sd_card.cpp:181:57: error: no match for 'operator=' (operand types are 'lv_color_t' and 'lv_color32_t')
  181 |             lv_color = lv_canvas_get_px(canvas, j, h - i);
      |                                                         ^
In file included from c:/Users/Professional/Documents/Arduino/libraries/lvgl/src/draw/lv_draw_buf.h:18,
                 from c:/Users/Professional/Documents/Arduino/libraries/lvgl/src/misc/lv_utils.h:18,
                 from c:/Users/Professional/Documents/Arduino/libraries/lvgl/lvgl.h:35,
                 from c:\Users\Professional\Documents\Arduino\libraries\lvgl\src/lvgl.h:16,
                 from C:\Users\Professional\Desktop\T-Display-S3-Pro-master\examples\factory\sd_card.h:9,
                 from C:\Users\Professional\Desktop\T-Display-S3-Pro-master\examples\factory\sd_card.cpp:3:
c:/Users/Professional/Documents/Arduino/libraries/lvgl/src/misc/lv_color.h:101:3: note: candidate: 'constexpr lv_color_t& lv_color_t::operator=(const lv_color_t&)'
  101 | } lv_color_t;
      |   ^~~~~~~~~~
c:/Users/Professional/Documents/Arduino/libraries/lvgl/src/misc/lv_color.h:101:3: note:   no known conversion for argument 1 from 'lv_color32_t' to 'const lv_color_t&'
c:/Users/Professional/Documents/Arduino/libraries/lvgl/src/misc/lv_color.h:101:3: note: candidate: 'constexpr lv_color_t& lv_color_t::operator=(lv_color_t&&)'
c:/Users/Professional/Documents/Arduino/libraries/lvgl/src/misc/lv_color.h:101:3: note:   no known conversion for argument 1 from 'lv_color32_t' to 'lv_color_t&&'
C:\Users\Professional\Desktop\T-Display-S3-Pro-master\examples\factory\sd_card.cpp:182:36: error: 'struct lv_color_t' has no member named 'ch'
  182 |             color.rgb.r = lv_color.ch.red;
      |                                    ^~
C:\Users\Professional\Desktop\T-Display-S3-Pro-master\examples\factory\sd_card.cpp:183:37: error: 'struct lv_color_t' has no member named 'ch'
  183 |             color.rgb.g = (lv_color.ch.green_h << 3 | lv_color.ch.green_l) & 0x3f;
      |                                     ^~
C:\Users\Professional\Desktop\T-Display-S3-Pro-master\examples\factory\sd_card.cpp:183:64: error: 'struct lv_color_t' has no member named 'ch'
  183 |             color.rgb.g = (lv_color.ch.green_h << 3 | lv_color.ch.green_l) & 0x3f;
      |                                                                ^~
C:\Users\Professional\Desktop\T-Display-S3-Pro-master\examples\factory\sd_card.cpp:184:36: error: 'struct lv_color_t' has no member named 'ch'
  184 |             color.rgb.b = lv_color.ch.blue;
      |                                    ^~
C:\Users\Professional\Desktop\T-Display-S3-Pro-master\examples\factory\factory.ino: In function 'void eeproom_init()':
C:\Users\Professional\Desktop\T-Display-S3-Pro-master\examples\factory\factory.ino:66:9: error: 'lv_memset_00' was not declared in this scope; did you mean 'lv_memset'?
   66 |         lv_memset_00(eeprom_buf, EEPROM_SIZE_MAX);
      |         ^~~~~~~~~~~~
      |         lv_memset
C:\Users\Professional\Desktop\T-Display-S3-Pro-master\examples\factory\factory.ino: In function 'bool initSensor()':
C:\Users\Professional\Desktop\T-Display-S3-Pro-master\examples\factory\factory.ino:196:9: error: 'class SensorLTR553' has no member named 'setPsLedCurrnet'; did you mean 'setPsLedCurrent'?
  196 |     als.setPsLedCurrnet(SensorLTR553::PS_LED_CUR_100MA);
      |         ^~~~~~~~~~~~~~~
      |         setPsLedCurrent
C:\Users\Professional\Desktop\T-Display-S3-Pro-master\examples\factory\factory.ino: In function 'void updateLightDected(lv_timer_t*)':
C:\Users\Professional\Desktop\T-Display-S3-Pro-master\examples\factory\factory.ino:255:27: error: invalid use of incomplete type 'lv_timer_t' {aka 'struct lv_timer_t'}
  255 |                 if(cnt * t->period > ps_time * 1000){
      |                           ^~
In file included from c:/Users/Professional/Documents/Arduino/libraries/lvgl/src/lv_init.h:17,
                 from c:/Users/Professional/Documents/Arduino/libraries/lvgl/lvgl.h:21,
                 from c:\Users\Professional\Documents\Arduino\libraries\lvgl\src/lvgl.h:16,
                 from C:\Users\Professional\Desktop\T-Display-S3-Pro-master\examples\factory\LV_Helper.h:12,
                 from C:\Users\Professional\Desktop\T-Display-S3-Pro-master\examples\factory\factory.ino:6:
c:/Users/Professional/Documents/Arduino/libraries/lvgl/src/misc/lv_types.h:112:16: note: forward declaration of 'lv_timer_t' {aka 'struct lv_timer_t'}
  112 | typedef struct lv_timer_t lv_timer_t;
      |                ^~~~~~~~~~
C:\Users\Professional\Desktop\T-Display-S3-Pro-master\examples\factory\factory.ino:265:27: error: invalid use of incomplete type 'lv_timer_t' {aka 'struct lv_timer_t'}
  265 |                 if(cnt * t->period > ps_time * 1000){
      |                           ^~
c:/Users/Professional/Documents/Arduino/libraries/lvgl/src/misc/lv_types.h:112:16: note: forward declaration of 'lv_timer_t' {aka 'struct lv_timer_t'}
  112 | typedef struct lv_timer_t lv_timer_t;
      |                ^~~~~~~~~~
C:\Users\Professional\Desktop\T-Display-S3-Pro-master\examples\factory\factory.ino: In function 'void camera_init()':
C:\Users\Professional\Desktop\T-Display-S3-Pro-master\examples\factory\factory.ino:350:5: error: 'ledcSetup' was not declared in this scope; did you mean 'ledc_stop'?
  350 |     ledcSetup(LEDC_WHITE_CH, 1000, 8);
      |     ^~~~~~~~~
      |     ledc_stop
C:\Users\Professional\Desktop\T-Display-S3-Pro-master\examples\factory\factory.ino:351:5: error: 'ledcAttachPin' was not declared in this scope; did you mean 'ledcAttach'?
  351 |     ledcAttachPin(CAMERA_WHITH_LED, LEDC_WHITE_CH);
      |     ^~~~~~~~~~~~~
      |     ledcAttach
C:\Users\Professional\Desktop\T-Display-S3-Pro-master\examples\factory\ui.cpp: In function 'void backgBut_explain(lv_obj_t*, lv_obj_t**, char*, lv_event_cb_t, void*, const void*, lv_coord_t, lv_coord_t)':
C:\Users\Professional\Desktop\T-Display-S3-Pro-master\examples\factory\ui.cpp:331:56: error: invalid conversion from 'int' to 'lv_obj_flag_t' [-fpermissive]
  331 |         lv_obj_add_flag(img_obj, LV_OBJ_FLAG_CLICKABLE | LV_OBJ_FLAG_ADV_HITTEST);
      |                                  ~~~~~~~~~~~~~~~~~~~~~~^~~~~~~~~~~~~~~~~~~~~~~~~
      |                                                        |
      |                                                        int
In file included from c:/Users/Professional/Documents/Arduino/libraries/lvgl/lvgl.h:39,
                 from c:\Users\Professional\Documents\Arduino\libraries\lvgl\src/lvgl.h:16,
                 from C:\Users\Professional\Desktop\T-Display-S3-Pro-master\examples\factory\sd_card.h:9,
                 from C:\Users\Professional\Desktop\T-Display-S3-Pro-master\examples\factory\ui.h:11,
                 from C:\Users\Professional\Desktop\T-Display-S3-Pro-master\examples\factory\ui.cpp:1:
c:/Users/Professional/Documents/Arduino/libraries/lvgl/src/core/lv_obj.h:240:52: note:   initializing argument 2 of 'void lv_obj_add_flag(lv_obj_t*, lv_obj_flag_t)'
  240 | void lv_obj_add_flag(lv_obj_t * obj, lv_obj_flag_t f);
      |                                      ~~~~~~~~~~~~~~^
C:\Users\Professional\Desktop\T-Display-S3-Pro-master\examples\factory\ui.cpp:333:109: error: invalid conversion from 'int' to 'lv_obj_flag_t' [-fpermissive]
  332 |         lv_obj_clear_flag(img_obj, LV_OBJ_FLAG_PRESS_LOCK | LV_OBJ_FLAG_CLICK_FOCUSABLE | LV_OBJ_FLAG_GESTURE_BUBBLE |
      |                                    ~~~~~~~~~~~~~~~~~~~~~~~~~~~~~~~~~~~~~~~~~~~~~~~~~~~~~~~~~~~~~~~~~~~~~~~~~~~~~~~~~~~
  333 |                           LV_OBJ_FLAG_SCROLLABLE | LV_OBJ_FLAG_SCROLL_ELASTIC | LV_OBJ_FLAG_SCROLL_MOMENTUM |
      |                           ~~~~~~~~~~~~~~~~~~~~~~~~~~~~~~~~~~~~~~~~~~~~~~~~~~~~~~~~~~~~~~~~~~~~~~~~~~~~~~~~~~^
      |                                                                                                             |
      |                                                                                                             int
  334 |                           LV_OBJ_FLAG_SCROLL_CHAIN);
      |                           ~~~~~~~~~~~~~~~~~~~~~~~~                                                   
c:/Users/Professional/Documents/Arduino/libraries/lvgl/src/core/lv_obj.h:247:55: note:   initializing argument 2 of 'void lv_obj_remove_flag(lv_obj_t*, lv_obj_flag_t)'
  247 | void lv_obj_remove_flag(lv_obj_t * obj, lv_obj_flag_t f);
      |                                         ~~~~~~~~~~~~~~^
C:\Users\Professional\Desktop\T-Display-S3-Pro-master\examples\factory\ui.cpp:355:84: error: invalid conversion from 'int' to 'lv_obj_flag_t' [-fpermissive]
  354 |         lv_obj_clear_flag(label_obj, LV_OBJ_FLAG_PRESS_LOCK | LV_OBJ_FLAG_GESTURE_BUBBLE | LV_OBJ_FLAG_SCROLLABLE |
      |                                      ~~~~~~~~~~~~~~~~~~~~~~~~~~~~~~~~~~~~~~~~~~~~~~~~~~~~~~~~~~~~~~~~~~~~~~~~~~~~~~
  355 |                           LV_OBJ_FLAG_SCROLL_ELASTIC | LV_OBJ_FLAG_SCROLL_MOMENTUM | LV_OBJ_FLAG_SCROLL_CHAIN);
      |                           ~~~~~~~~~~~~~~~~~~~~~~~~~~~~~~~~~~~~~~~~~~~~~~~~~~~~~~~~~^~~~~~~~~~~~~~~~~~~~~~~~~~
      |                                                                                    |
      |                                                                                    int
c:/Users/Professional/Documents/Arduino/libraries/lvgl/src/core/lv_obj.h:247:55: note:   initializing argument 2 of 'void lv_obj_remove_flag(lv_obj_t*, lv_obj_flag_t)'
  247 | void lv_obj_remove_flag(lv_obj_t * obj, lv_obj_flag_t f);
      |                                         ~~~~~~~~~~~~~~^
C:\Users\Professional\Desktop\T-Display-S3-Pro-master\examples\factory\ui.cpp: In function 'void moveup_Animation(lv_obj_t*, int)':
C:\Users\Professional\Desktop\T-Display-S3-Pro-master\examples\factory\ui.cpp:361:81: error: 'lv_mem_alloc' was not declared in this scope; did you mean 'lv_realloc'?
  361 |     ui_anim_user_data_t *PropertyAnimation_0_user_data = (ui_anim_user_data_t *)lv_mem_alloc(sizeof(ui_anim_user_data_t));
      |                                                                                 ^~~~~~~~~~~~
      |                                                                                 lv_realloc
C:\Users\Professional\Desktop\T-Display-S3-Pro-master\examples\factory\ui.cpp: In function 'void movedown_Animation(lv_obj_t*, int)':
C:\Users\Professional\Desktop\T-Display-S3-Pro-master\examples\factory\ui.cpp:383:81: error: 'lv_mem_alloc' was not declared in this scope; did you mean 'lv_realloc'?
  383 |     ui_anim_user_data_t *PropertyAnimation_0_user_data = (ui_anim_user_data_t *)lv_mem_alloc(sizeof(ui_anim_user_data_t));
      |                                                                                 ^~~~~~~~~~~~
      |                                                                                 lv_realloc
C:\Users\Professional\Desktop\T-Display-S3-Pro-master\examples\factory\ui.cpp: In function 'void prompt_label_timer(lv_timer_t*)':
C:\Users\Professional\Desktop\T-Display-S3-Pro-master\examples\factory\ui.cpp:459:29: error: invalid use of incomplete type 'lv_timer_t' {aka 'struct lv_timer_t'}
  459 |     lv_obj_del((lv_obj_t *)t->user_data);
      |                             ^~
In file included from c:/Users/Professional/Documents/Arduino/libraries/lvgl/src/lv_init.h:17,
                 from c:/Users/Professional/Documents/Arduino/libraries/lvgl/lvgl.h:21:
c:/Users/Professional/Documents/Arduino/libraries/lvgl/src/misc/lv_types.h:112:16: note: forward declaration of 'lv_timer_t' {aka 'struct lv_timer_t'}
  112 | typedef struct lv_timer_t lv_timer_t;
      |                ^~~~~~~~~~
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

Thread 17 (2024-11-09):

BOARD_TOUCH_IRQ in utilities.h

kc427hk, 2024-11-09:
Hi all,

  The file utilities.h in the example folder, the BOARD_TOUCH_IRQ is set to 7, GPIO7, but when I check the schematic, shouldn't it be GPIO21 ?

  Also, anyone know how to put the device in deep sleep, and then wake up by touching the screen?  How to do it properly?  I have tried putting it in deep sleep, but it would wake up automatically after about 5 seconds.

  Here is my code to put ESP32 into sleep:

```
void GoToSleepNow(void)
{
  // Erase the display.
  tft.fillScreen(TFT_BLACK);

  // LCD off.
  digitalWrite(TFT_BL, LOW);

  // Delay.
  delay(2000);

  // Enable touch sleep.
  touch.sleep();

  // Set wake up source fo the sleep mode.
  gpio_hold_en((gpio_num_t)BOARD_TOUCH_RST);
  //gpio_deep_sleep_hold_en();
  esp_sleep_enable_ext0_wakeup((gpio_num_t)BOARD_TOUCH_IRQ, 0);
  //esp_sleep_enable_ext0_wakeup((gpio_num_t)BOARD_TOUCH_IRQ, 1);   // 1, keep sleeping and won't wake up anymore
  esp_deep_sleep_start(); 
}
```

thanks

lewisxhe, 2024-11-11:
The touch terminal pin is 21, which has been updated

Touch wake-up, touch cannot be set to sleep.

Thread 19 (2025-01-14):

unrecognisable issue

sujay119, 2025-01-14:
Hi ,
I’m new to the ESP32 world, and I recently got a LilyGo T-Display S3 Pro board to create a photo viewer that reads images from an SD card.

Initially, I uploaded a simple SD card reading code, and it worked fine. However, after that, the board started showing errors, and now it won’t start at all.

If I try uploading another code, it throws GPIO errors.
If I fix those, it says the T-Display S3 Pro setup is not selected, even though I selected it in the configuration.
I’m stuck and don’t know how to proceed. Any help would be appreciated!

Here’s what I’ve tried so far:

Ensured the correct board is selected in the Arduino IDE.
Verified the User_Setup_Select.h file in the TFT_eSPI library to confirm the correct setup is uncommented.
Reinstalled the drivers and libraries.
My Setup:
Board: LilyGo T-Display S3 Pro
IDE: Arduino IDE

CODE:
#include <TFT_eSPI.h>
#include <SD.h>

#define SD_CS 5  // Adjust to your SD card CS pin

TFT_eSPI tft = TFT_eSPI();

void setup() {
  Serial.begin(115200);

  // Initialize TFT display
  tft.begin();
  tft.setRotation(1);
  tft.fillScreen(TFT_BLACK);

  // Initialize SD card
  if (!SD.begin(SD_CS)) {
    tft.fillScreen(TFT_RED);
    tft.setTextColor(TFT_WHITE, TFT_BLACK);
    tft.drawString("SD Init Failed!", 10, 10);
    while (true);
  }

  tft.setTextColor(TFT_WHITE, TFT_BLACK);
  tft.drawString("SD Initialized!", 10, 10);

  // Test: List files on the SD card
  File root = SD.open("/");
  tft.drawString("Files on SD:", 10, 30);
  int y = 50;
  while (true) {
    File file = root.openNextFile();
    if (!file) break;
    tft.drawString(file.name(), 10, y);
    y += 20;
    file.close();
  }
}

void loop() {}
AFTER THIS IT STARTED

sujay119, 2025-01-14:
can you guys please help

sujay119, 2025-01-14:
and if you can provide skype or discord to chat live

lewisxhe, 2025-01-14:
Delete all libraries and re-copy the copy provided by this repository. Do not upgrade the library version.

sujay119, 2025-01-14:
> Delete all libraries and re-copy the copy provided by this repository. Do not upgrade the library version.

ok

sujay119, 2025-01-14:
In file included from c:\Users\v.sujay\Documents\Arduino\libraries\TFT_eSPI\TFT_eSPI.h:97,
                 from c:\Users\v.sujay\Documents\Arduino\libraries\TFT_eSPI\TFT_eSPI.cpp:16:
c:\Users\v.sujay\Documents\Arduino\libraries\TFT_eSPI\Processors/TFT_eSPI_ESP32_S3.c: In function 'void dc_callback(spi_transaction_t*)':
c:\Users\v.sujay\Documents\Arduino\libraries\TFT_eSPI\Processors/TFT_eSPI_ESP32_S3.h:203:22: error: 'GPIO' was not declared in this scope
  203 |         #define DC_D GPIO.out_w1ts = (1 << TFT_DC)//;GPIO.out_w1ts = (1 << TFT_DC)
      |                      ^~~~
c:\Users\v.sujay\Documents\Arduino\libraries\TFT_eSPI\Processors/TFT_eSPI_ESP32_S3.c:816:28: note: in expansion of macro 'DC_D'
  816 |   if ((bool)spi_tx->user) {DC_D;}
      |                            ^~~~
c:\Users\v.sujay\Documents\Arduino\libraries\TFT_eSPI\Processors/TFT_eSPI_ESP32_S3.h:202:22: error: 'GPIO' was not declared in this scope
  202 |         #define DC_C GPIO.out_w1tc = (1 << TFT_DC)//;GPIO.out_w1tc = (1 << TFT_DC)
      |                      ^~~~
c:\Users\v.sujay\Documents\Arduino\libraries\TFT_eSPI\Processors/TFT_eSPI_ESP32_S3.c:817:9: note: in expansion of macro 'DC_C'
  817 |   else {DC_C;}
      |         ^~~~
c:\Users\v.sujay\Documents\Arduino\libraries\TFT_eSPI\TFT_eSPI.cpp: In member function 'void TFT_eSPI::begin_tft_write()':
c:\Users\v.sujay\Documents\Arduino\libraries\TFT_eSPI\Processors/TFT_eSPI_ESP32_S3.h:239:22: error: 'GPIO' was not declared in this scope
  239 |         #define CS_L GPIO.out1_w1tc.val = (1 << (TFT_CS - 32)); GPIO.out1_w1tc.val = (1 << (TFT_CS - 32))
      |                      ^~~~
c:\Users\v.sujay\Documents\Arduino\libraries\TFT_eSPI\TFT_eSPI.cpp:80:5: note: in expansion of macro 'CS_L'
   80 |     CS_L;
      |     ^~~~
c:\Users\v.sujay\Documents\Arduino\libraries\TFT_eSPI\TFT_eSPI.cpp: In member function 'virtual void TFT_eSPI::begin_nin_write()':
c:\Users\v.sujay\Documents\Arduino\libraries\TFT_eSPI\Processors/TFT_eSPI_ESP32_S3.h:239:22: error: 'GPIO' was not declared in this scope
  239 |         #define CS_L GPIO.out1_w1tc.val = (1 << (TFT_CS - 32)); GPIO.out1_w1tc.val = (1 << (TFT_CS - 32))
      |                      ^~~~
c:\Users\v.sujay\Documents\Arduino\libraries\TFT_eSPI\TFT_eSPI.cpp:92:5: note: in expansion of macro 'CS_L'
   92 |     CS_L;
      |     ^~~~
c:\Users\v.sujay\Documents\Arduino\libraries\TFT_eSPI\TFT_eSPI.cpp: In member function 'void TFT_eSPI::end_tft_write()':
c:\Users\v.sujay\Documents\Arduino\libraries\TFT_eSPI\Processors/TFT_eSPI_ESP32_S3.h:240:22: error: 'GPIO' was not declared in this scope
  240 |         #define CS_H GPIO.out1_w1ts.val = (1 << (TFT_CS - 32))//;GPIO.out1_w1ts.val = (1 << (TFT_CS - 32))
      |                      ^~~~
c:\Users\v.sujay\Documents\Arduino\libraries\TFT_eSPI\TFT_eSPI.cpp:106:7: note: in expansion of macro 'CS_H'
  106 |       CS_H;
      |       ^~~~
c:\Users\v.sujay\Documents\Arduino\libraries\TFT_eSPI\TFT_eSPI.cpp: In member function 'virtual void TFT_eSPI::end_nin_write()':
c:\Users\v.sujay\Documents\Arduino\libraries\TFT_eSPI\Processors/TFT_eSPI_ESP32_S3.h:240:22: error: 'GPIO' was not declared in this scope
  240 |         #define CS_H GPIO.out1_w1ts.val = (1 << (TFT_CS - 32))//;GPIO.out1_w1ts.val = (1 << (TFT_CS - 32))
      |                      ^~~~
c:\Users\v.sujay\Documents\Arduino\libraries\TFT_eSPI\TFT_eSPI.cpp:121:7: note: in expansion of macro 'CS_H'
  121 |       CS_H;
      |       ^~~~
c:\Users\v.sujay\Documents\Arduino\libraries\TFT_eSPI\TFT_eSPI.cpp: In member function 'void TFT_eSPI::begin_tft_read()':
c:\Users\v.sujay\Documents\Arduino\libraries\TFT_eSPI\Processors/TFT_eSPI_ESP32_S3.h:239:22: error: 'GPIO' was not declared in this scope
  239 |         #define CS_L GPIO.out1_w1tc.val = (1 << (TFT_CS - 32)); GPIO.out1_w1tc.val = (1 << (TFT_CS - 32))
      |                      ^~~~
c:\Users\v.sujay\Documents\Arduino\libraries\TFT_eSPI\TFT_eSPI.cpp:141:5: note: in expansion of macro 'CS_L'
  141 |     CS_L;
      |     ^~~~
c:\Users\v.sujay\Documents\Arduino\libraries\TFT_eSPI\TFT_eSPI.cpp: In member function 'void TFT_eSPI::end_tft_read()':
c:\Users\v.sujay\Documents\Arduino\libraries\TFT_eSPI\Processors/TFT_eSPI_ESP32_S3.h:240:22: error: 'GPIO' was not declared in this scope
  240 |         #define CS_H GPIO.out1_w1ts.val = (1 << (TFT_CS - 32))//;GPIO.out1_w1ts.val = (1 << (TFT_CS - 32))
      |                      ^~~~
c:\Users\v.sujay\Documents\Arduino\libraries\TFT_eSPI\TFT_eSPI.cpp:161:7: note: in expansion of macro 'CS_H'
  161 |       CS_H;
      |       ^~~~
c:\Users\v.sujay\Documents\Arduino\libraries\TFT_eSPI\TFT_eSPI.cpp: In member function 'void TFT_eSPI::writecommand(uint8_t)':
c:\Users\v.sujay\Documents\Arduino\libraries\TFT_eSPI\Processors/TFT_eSPI_ESP32_S3.h:202:22: error: 'GPIO' was not declared in this scope
  202 |         #define DC_C GPIO.out_w1tc = (1 << TFT_DC)//;GPIO.out_w1tc = (1 << TFT_DC)
      |                      ^~~~
c:\Users\v.sujay\Documents\Arduino\libraries\TFT_eSPI\TFT_eSPI.cpp:984:3: note: in expansion of macro 'DC_C'
  984 |   DC_C;
      |   ^~~~
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
sujay119, 2025-01-16:
so i should store every image by name of 480x222.jpg

sujay119, 2025-01-16:
then how to access other files

sujay119, 2025-01-16:
is there any way i can see another images

lewisxhe, 2025-01-16:
I only provide a minimal sample application. For the rest, you need to read the SD content yourself to determine the image to access. You need to modify the code yourself.

sujay119, 2025-01-16:
ok ill try out now if i find error ill contact you

sujay119, 2025-01-16:
i read and uploaded the code
#include <TFT_eSPI.h>
#include <FS.h>
#include <SD.h>
#include <Wire.h>
#include <Adafruit_FT6206.h>
#include <TJpg_Decoder.h>

// Define TFT and touch
TFT_eSPI tft = TFT_eSPI();
Adafruit_FT6206 touch = Adafruit_FT6206();

#define SD_CS 10                      // SD card chip select pin
#define SCREEN_WIDTH 222              // Width is 222
#define SCREEN_HEIGHT 480             // Height is 480

String imageDir = "/images";          // Directory where images are stored
String tempImageName = "/480x222.jpg"; // Required image filename
int imageIndex = 0;
String imageList[50];                 // Array to store image file paths
int imageCount = 0;                   // Number of images in the directory

// Callback for drawing JPEG on TFT
bool tftDrawCallback(int16_t x, int16_t y, uint16_t w, uint16_t h, uint16_t *bitmap) {
  if (y >= SCREEN_HEIGHT) return 0; // Stop drawing if outside display area
  tft.pushImage(x, y, w, h, bitmap);
  return 1;
}

void setup() {
  Serial.begin(115200);

  // Initialize TFT
  tft.init();
  tft.setRotation(3); // Rotate the screen to match the 480x222 orientation

  // Initialize touch
  if (!touch.begin()) {
    Serial.println("Touch initialization failed!");
    while (1);
  }

  // Initialize SD card
  if (!SD.begin(SD_CS)) {
    Serial.println("SD card initialization failed!");
    while (1);
  }

  // Initialize JPEG decoder
  TJpgDec.setJpgScale(1); // No scaling
  TJpgDec.setCallback(tftDrawCallback);

  // Load list of images
  loadImages();

  // Display the first image
  if (imageCount > 0) {
    displayImage(imageList[imageIndex]);
  } else {
    Serial.println("No images found in the directory!");
  }
}

void loadImages() {
  imageCount = 0;
  File root = SD.open(imageDir);

  if (!root) {
    Serial.println("Failed to open image directory!");
    return;
  }

  File file = root.openNextFile();
  while (file && imageCount < 50) {
    if (!file.isDirectory()) {
      String fileName = file.name();
      if (fileName.endsWith(".jpg")) {
        // Replace spaces and special characters in the file name
        fileName.replace(" ", "_");  // Optional: Replace spaces with underscores
        fileName.replace("(", "");   // Remove any parentheses
        fileName.replace(")", "");   // Remove any parentheses
        imageList[imageCount++] = fileName;
        Serial.println("Found image: " + fileName);  // Log the found image name
      }
    }
    file = root.openNextFile();
  }

  root.close();
  Serial.printf("Found %d images in the directory.\n", imageCount);
}

void displayImage(const String &path) {
  // Rename the selected image to the required filename
  if (SD.exists(tempImageName)) {
    SD.remove(tempImageName);
  }

  if (SD.rename(path, tempImageName)) {
    // Display the image using the renamed file
    tft.fillScreen(TFT_BLACK);
    if (TJpgDec.drawJpg(0, 0, tempImageName) != 0) {
      Serial.println("Error decoding JPEG image!");
    }
  } else {
    Serial.println("Failed to rename image to temporary name!");
  }
}

void handleTouch() {
  if (!touch.touched()) return;

  TS_Point p = touch.getPoint();
  int x = p.x;

  if (x < 50) {
    // Swipe left
    if (imageIndex > 0) {
      imageIndex--;
      displayImage(imageList[imageIndex]);
    }
  } else if (x > SCREEN_WIDTH - 50) {
    // Swipe right
    if (imageIndex < imageCount - 1) {
      imageIndex++;
      displayImage(imageList[imageIndex]);
    }
  }
}

void loop() {
  handleTouch();
}

sujay119, 2025-01-16:
it gave me this image after uploding

sujay119, 2025-01-16:
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

sujay119, 2025-01-17:
ONE SMALL DOUBT I REPLACED THE BATTERY  WITH A 1200mah battery the battery health indicator is fluctuating once shows 100, once 32,once 0(still working) . is it the issue of the battery

lewisxhe, 2025-01-20:
Check the battery connector for contact problems

sujay119, 2025-06-25:
@lewisxhe the display of the lilygo s3 pro got stuck what can I do to bring it functionback i was using it as usual but suddenly the screen got stuck .It's getting turned on but touch display is not working, though I handled it very carefully

lewisxhe, 2025-06-27:
You can try to scan the I2C bus to see if you can see the touch device

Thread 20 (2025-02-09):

Power switch stops working to turn on s3 pro

HoaxParagon, 2025-02-09:
I've enabled the pmu and made it enable charging but the problem is that without a usb-c connector to start the thing it doesn't work. The power switch doesn't do anything any more. I've uploaded custom code to the thing, more specifically the ESP32 Marauder software that I ported to the S3 pro. I'm not done porting it yet but now the button doesn't work to power the unit.

HoaxParagon, 2025-02-13:
I think it's something in software because if the switch is on when the usb-c is unplugged, it stays on. Must be something in software.

lewisxhe, 2025-02-13:
If so, then you have to consider this, are you using ArduinoIDE?? If yes, then set USB CDC ON BOOT to Disable

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

HoaxParagon, 2025-02-13:
I've done this and reuploaded via arduino IDE, and the button still won't turn on the unit.

lewisxhe, 2025-02-13:
Then there is only one way to test it. You need a USB2TTL, connect it to the Qwiic 43 (TX), 44 (RX) of DISPLAY, and monitor whether the ESP is started.

Remember the connection of RX and TX, to be opposite,
USB2TTL RX -> DISPLAY TX
USB2TTL TX -> DISPLAY RX

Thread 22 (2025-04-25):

LilyGo S3 Pro Camera - does connect / disconnect to laptop (every 3 sec) - does not boot

Kingair001, 2025-04-25:
Dear,
I bought a LilyGo S3 Pro Camera via AliExpress and the people asked me to contact you.
My LilyGo S3 Pro Camera does not boot, it does connect / disconnects every 3 seconds from my laptop
How can I solve this please ?

lewisxhe, 2025-04-25:
You should check if your Arduino IDE options match the example. Constant disconnection is a sign of program crash.
https://github.com/Xinyuan-LilyGO/T-Display-S3-Pro#6%EF%B8%8F%E2%83%A3-faq

Kingair001, 2025-04-25:
I have a black screen, nothing is happening
I am not Bill Gates/ into IT, so please explain each step
I bought it new
Plugged it in, and this is what happens

lewisxhe, 2025-04-25:
You just got it?

Haven't uploaded any sketches yet?Just got it?

Haven't uploaded any sketches?

You can try uploading any factory firmware sketch to see if the screen can display normally
https://github.com/Xinyuan-LilyGO/T-Display-S3-Pro/tree/master/firmware/v1.1

Kingair001, 2025-04-25:
Not just but I was waiting on the people frol LilyGo what to do
They adviced me to open an Issue here

Now it connects/disconnects every 3 seconds, so how will I be qable to upload anything?

lewisxhe, 2025-04-25:
You need enter esp to download mode

1. Connect the board via the USB cable
2. Press and hold the BOOT button , While still pressing the BOOT button, press RST
3. Release the RST
4. Release the BOOT button
5. Upload firmware

Follow the above sequence, and the USB port will be fixed and no longer flash.

Download this [firmware](https://github.com/Xinyuan-LilyGO/T-Display-S3-Pro/blob/master/firmware/v1.1/UnitTest_V1.1_DisChg_Debug.bin)

Follow this README and upload the firmware to the esp device through esp download tools
https://github.com/Xinyuan-LilyGO/T-Display-S3-Pro/tree/master/firmware

After uploading, press the RST button to restart the device. The screen should show

Kingair001, 2025-04-25:
I can not download the flash tool -> error 403 foridden !
I have the firmware you provided via the link

lewisxhe, 2025-04-25:
OK, I can download it. Or you can use the online download tool, check here, it is the same method, please note that the write address must be 0
https://espressif.github.io/esptool-js/

Kingair001, 2025-04-25:
Nothing happens, it does still the same: connect / disconnect
Do you have a link for the flash firmware tool, so I can try that ?

lewisxhe, 2025-04-25:
First step If I put the ESP into download mode, does it still disconnect and connect repeatedly?

Kingair001, 2025-04-25:
Yes it does !

lewisxhe, 2025-04-25:
Still? ?

Then it may be that the steps are incorrect.
Please confirm whether you have followed the steps below

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

Kingair001, 2025-04-25:
Now red light flickers - really fast

lewisxhe, 2025-04-25:
The red light is just a battery indicator, it will flash when there is no battery. Have you entered the download mode correctly now?

Kingair001, 2025-04-25:
It keeps doing the same
Connect / disconnect
I hear the sound every 3 sec

lewisxhe, 2025-04-25:
OK, please record a video of the device failing to enter download mode, send it to the dealer to confirm that it is damaged, and then they will handle the after-sales replacement package for you.

Kingair001, 2025-04-25:
I already did that, I'll send them a screenshot of this conversation
Hopefully it get's solved
Thanks

lewisxhe, 2025-04-25:
Yes. The dealer will communicate with you later.

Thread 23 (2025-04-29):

Touch Controller - exact model / datasheet

aponert, 2025-04-29:
Hello, since I would like to write my code using esp-idf I need to know which exact Touch Driver The T-Display-S3-Pro uses.
The touch lib mentions support for several controllers ([CST328, CST816, CST820, GT911, FT3267, FT5x06](lib/TouchLib/))

In the [TouchLib Example](lib/TouchLib/example/demo/demo.ino)  GT911 is defined. However, in the other [Touch Example](examples/CapacitiveTouch) TouchDrvCSTXXX is mentioned, but not specifically which one.

Can anyone hint me to the exact Touch Controller model so that I can search a datasheet?

lewisxhe, 2025-04-30:
The touch model is CST226SE, and the data sheet is currently only this one.
There is not much information about the manufacturer of this touch chip on the Internet
https://github.com/lewisxhe/SensorLib/blob/master/datasheet/%E6%B5%B7%E6%A0%8E%E5%88%9B%E8%A7%A6%E6%91%B8%E8%8A%AF%E7%89%87%E7%A7%BB%E6%A4%8D%E6%89%8B%E5%86%8C-v3.5-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

Closed 2025-04-30.

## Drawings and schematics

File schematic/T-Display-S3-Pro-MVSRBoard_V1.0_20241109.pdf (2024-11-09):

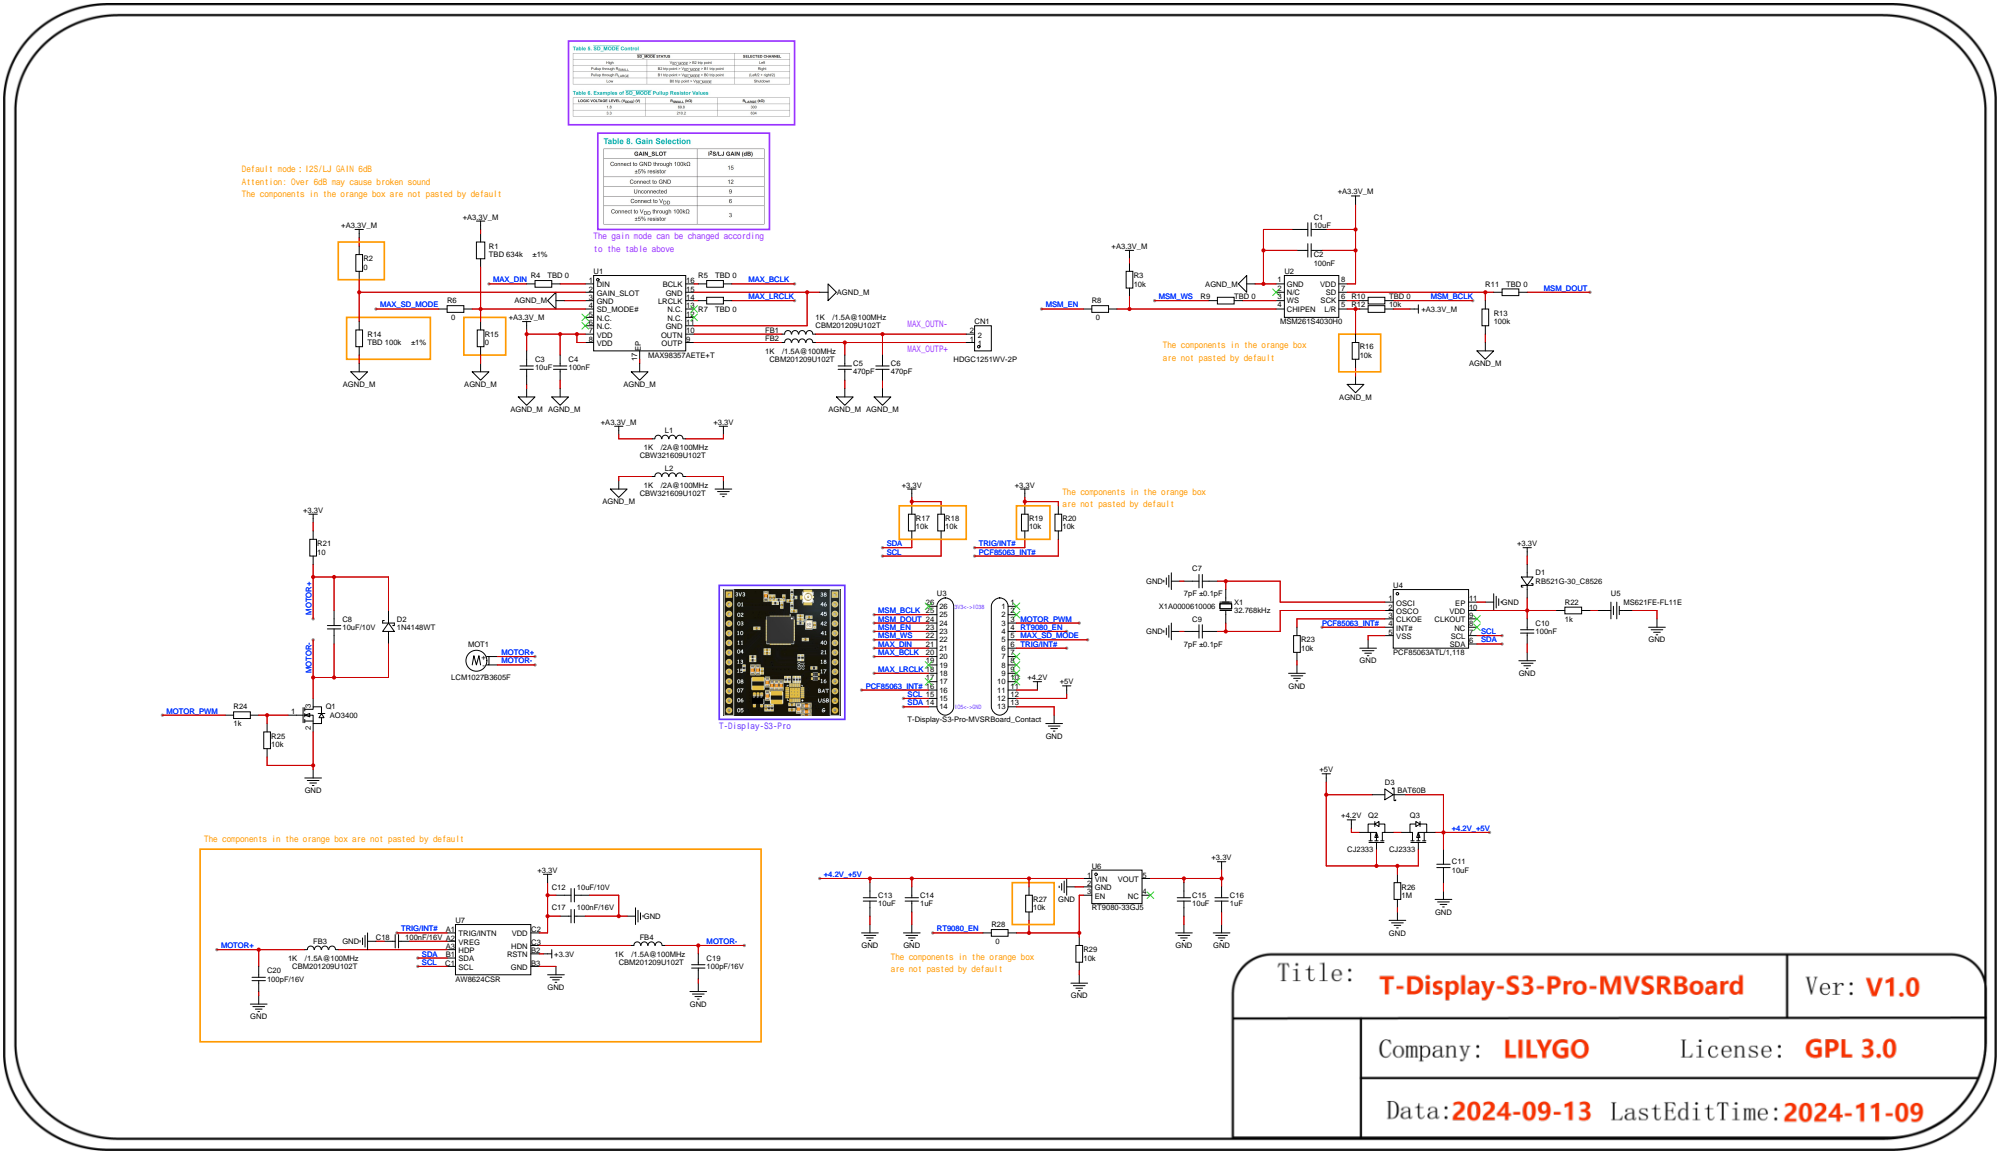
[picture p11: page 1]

Default mode：I2S/LJ GAIN 6dB
Attention: Over 6dB may cause broken sound
The components in the orange box are not pasted by default

The gain mode can be changed according
to the table above

OUTN 10 GND 11 N.C. 12 N.C. 13 LRCLK 14 GND 15 BCLK 16

The components in the orange box
are not pasted by default

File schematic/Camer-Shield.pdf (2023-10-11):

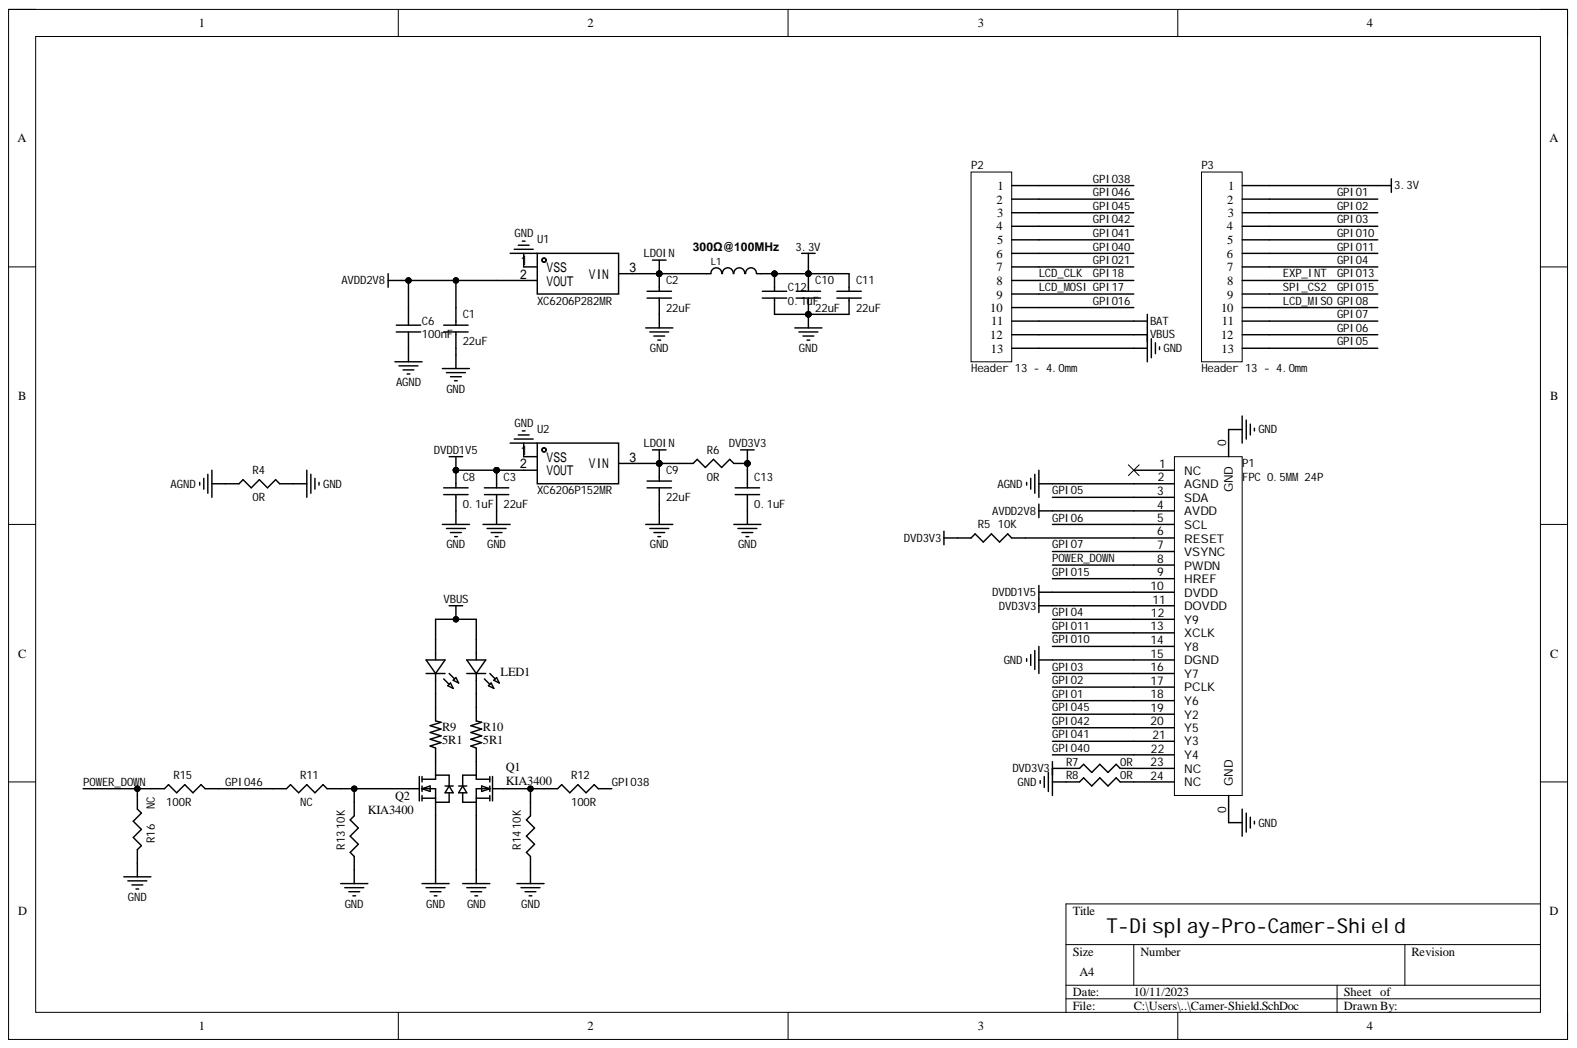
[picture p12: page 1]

Title
T-Display-Pro-Camer-Shield

Size A4 | Number | Revision

Date: 10/11/2023 | Sheet of
File: C:\Users\..\Camer-Shield.SchDoc | Drawn By:

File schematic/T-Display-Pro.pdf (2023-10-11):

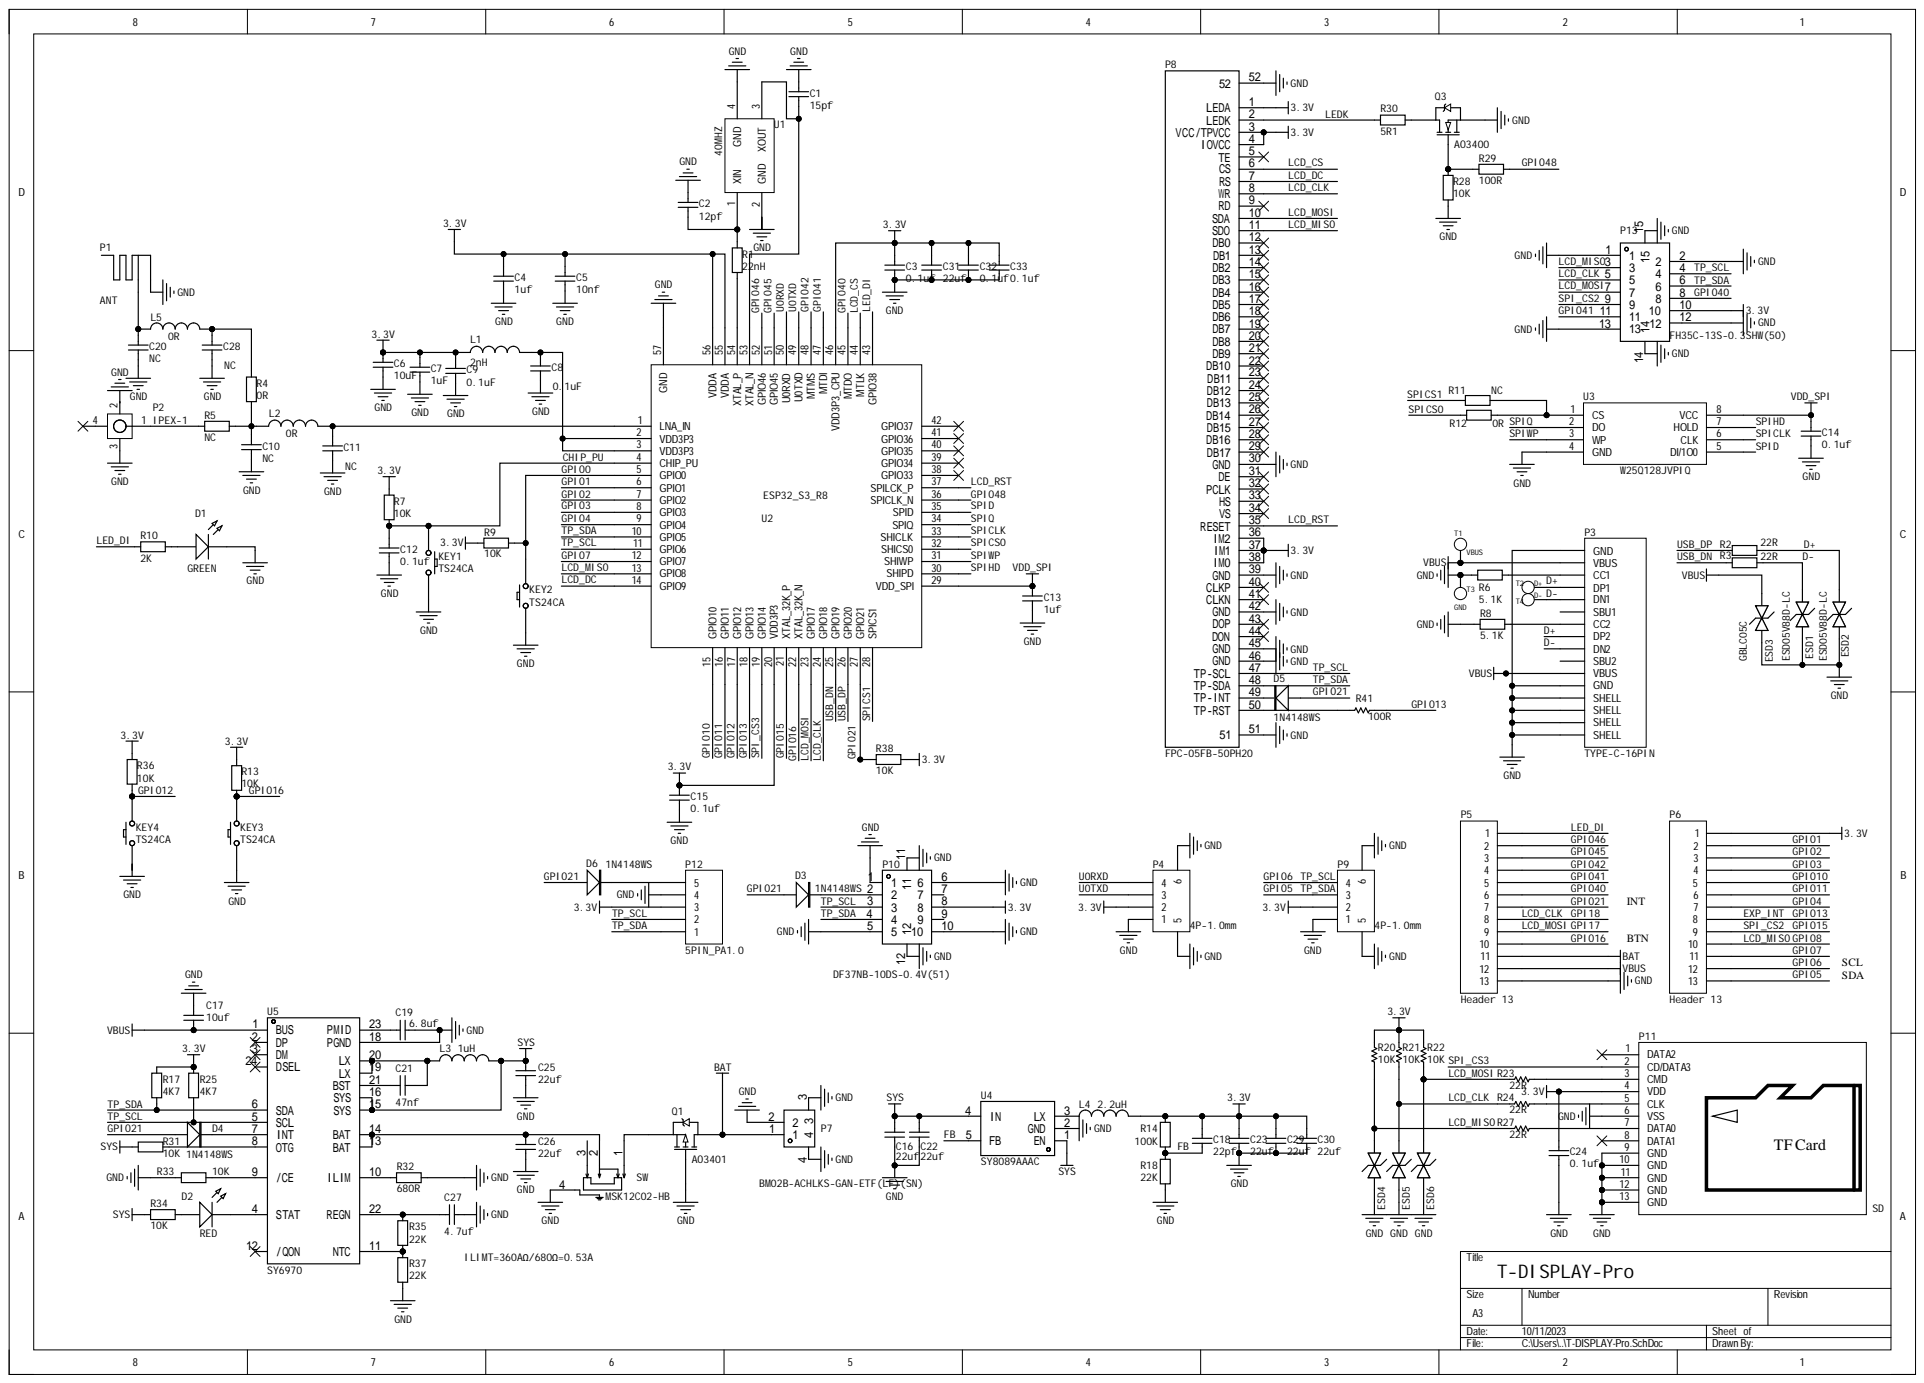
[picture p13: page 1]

GPIO38 43 MTLK 44 MTDO 45 VDD3P3_CPU 46 MTDI 47 MTMS 48 U0TXD 49 U0RXD 50 GPIO45 51 GPIO46 52 XTAL_N 53 XTAL_P 54 VDDA 55 VDDA 56

SPICS1 28 VDD_SPI 29 SHIPD 30 SHIWP 31 SHICS0 32 SHICLK 33 SPIQ 34 SPID 35 SPICLK_N 36 SPILCK_P 37 GPIO33 38 GPIO34 39 GPIO35 40

BM02B-ACHLKS-GAN-ETF(LF)(SN)

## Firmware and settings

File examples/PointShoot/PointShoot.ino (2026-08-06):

/**
 * PointShoot - T-Display-S3-Pro + OV5640 camera shield as a point-and-shoot.
 *
 *   btn1 (GPIO0)  WIFI  - bottom-left  - photo-transfer AP, gallery at 192.168.4.1
 *   btn2 (GPIO12) not populated on this board
 *   btn3 (GPIO16) SHOOT - bottom-right - full-res JPEG to SD if present, else flash
 *   touch          tap viewfinder = shutter, tap strip above it = torch
 *
 * Camera pin map and PMU setup lifted from the CameraShield example.
 */
#include <Arduino.h>
#include <esp_camera.h>
#include <TJpg_Decoder.h>
#include <TouchDrvCSTXXX.hpp>
#include <ESP32_OV5640_AF.h>
#include <TFT_eSPI.h>
#include <WiFi.h>
#include <WebServer.h>
#include <DNSServer.h>
#include <XPowersLib.h>
#include <SPI.h>
#include <SD.h>
#include <FFat.h>
#include <Preferences.h>
#include <sys/time.h>
#include "utilities.h"

#define AP_SSID      "TDisplayCam"
#define AP_PASS      "photos1234"   // >=8 chars or softAP stays open

// How the sensor is mounted relative to the panel is a property of the shield,
// not something to guess at: orient is one element of the dihedral group,
// settable live by sending '0'-'7' over serial.
//   bits 0-1  quarter turns clockwise applied when displaying
//   bit  2    mirror horizontally first
// All 8 are reachable, so exactly one of them is correct. The sensor's own
// mirror/flip registers are forced off so this is the only thing acting.
// Measured on this shield: the sensor image needs a vertical flip. It first
// looked like a horizontal mirror, but that was judged against a display that
// was itself rotated 180; with the panel the right way up the correction is
// R180 composed with that mirror, which is exactly a vflip.
#define MOUNT_MIRROR 0
#define MOUNT_VFLIP  1

#define ORIENT_DEFAULT 0
static uint8_t orient = ORIENT_DEFAULT;

// Everything runs at 10MHz XCLK. Measured on this sensor: at 20MHz, full-res
// frames come out at 0.56-0.61x the preview's mean brightness at every
// resolution, because the full-res frame timing caps integration. At 10MHz the
// still matches the preview (ratio 1.01); 8MHz overshoots to 1.14.
#define CAM_XCLK_HZ    (10 * 1000000)
#define STILL_SIZE     FRAMESIZE_QSXGA   // 2560x1920
#define PREVIEW_SIZE   FRAMESIZE_QVGA    // 320x240
#define SETTLE_FRAMES  0                 // frames to drop after a size change

// The camera is initialised once, in JPEG mode at the largest frame size, and
// a shot is just a set_framesize() away. Tearing it down and re-initialising
// per shot cost ~2.5s of the ~2.9s shutter lag, and threw away the converged
// exposure and the uploaded autofocus firmware every time.
// Panel the right way up: text reads correctly and the SHOOT/WIFI labels land
// on the bottom edge, over btn1 (left) and btn3 (right).
#define DISPLAY_ROTATION 0

#define ORI_ROT    (orient & 3)
#define ORI_MIRROR ((orient >> 2) & 1)

// EXIF orientation for each mode, so stills come out upright in Photos without
// rotating 5M pixels on the ESP32. Index is (mirror << 2) | rot.
static const uint8_t EXIF_FOR_ORIENT[8] = {1, 6, 3, 8, 2, 7, 4, 5};
#define EXIF_ORIENT (EXIF_FOR_ORIENT[orient & 7])

#define SRC_W 320
#define SRC_H 240
#define VF_W  222                       // preview is fitted to the panel width
#define VF_H_MAX 296                    // 3:4 (quarter-turned), the taller case
static int vfH = VF_H_MAX;
static int vfY = (480 - VF_H_MAX) / 2;

TFT_eSPI    tft;
PowersSY6970 PMU;
WebServer   server(80);
DNSServer   dns;
Preferences prefs;

static fs::FS     *store    = nullptr;
static const char *storeName = "none";
static uint16_t   *vf       = nullptr;   // rotated viewfinder buffer (PSRAM)
static bool        wifiOn   = false;
static char        status[48] = "";
static uint16_t    battMv     = 0;
static char        sdInfo[48] = "not probed";
static uint16_t    photoCount = 0;
static uint32_t    photoBytes = 0;
static uint8_t     battPct    = 0;
static bool        battChg    = false;

// The SY6970 has no fuel gauge, so state of charge is inferred from voltage
// against a LiPo discharge curve. That sags under load - a capture pulls the
// reading down - so the voltage is smoothed before conversion.
static uint8_t battPercent(uint16_t mv)
{
    static const uint16_t curve[][2] = {
        {3300, 0}, {3600, 10}, {3700, 25}, {3750, 40},
        {3850, 60}, {3950, 75}, {4050, 90}, {4200, 100},
    };
    const int n = sizeof(curve) / sizeof(curve[0]);
    if (mv <= curve[0][0]) return 0;
    for (int i = 1; i < n; i++) {
        if (mv < curve[i][0]) {
            uint16_t v0 = curve[i - 1][0], p0 = curve[i - 1][1];
            return p0 + (uint32_t)(mv - v0) * (curve[i][1] - p0) / (curve[i][0] - v0);
        }
    }
    return 100;
}

// Percentage is meaningless while the charger holds the terminal voltage up.
static const char *battPctStr()
{
    static char b[8];
    if (battChg) strcpy(b, "chg");
    else         snprintf(b, sizeof(b), "%u%%", battPct);
    return b;
}

static void pollBattery()
{
    static uint32_t next = 0;
    if (millis() < next) return;
    next = millis() + 2000;

    uint16_t mv = PMU.getBattVoltage();
    if (mv < 2500) return;                       // no battery / bad reading

    // While charging the terminal voltage is held up by the charger and is not
    // the cell's resting voltage, so the curve would read near-full whatever
    // the real charge. Only convert while discharging, and drop the smoothing
    // history when the state flips so the first reading off USB is honest.
    bool chg = PMU.isCharging() || PMU.isVbusIn();
    if (chg != battChg) { battChg = chg; battMv = 0; }

    battMv = battMv ? (battMv * 7 + mv) / 8 : mv;
    if (!battChg) battPct = battPercent(battMv);
}

// ---------------------------------------------------------------- camera ---

static camera_config_t baseConfig()
{
    camera_config_t c = {};
    c.ledc_channel  = LEDC_CHANNEL_0;
    c.ledc_timer    = LEDC_TIMER_0;
    c.pin_d0 = CAMERA_PIN_Y2;  c.pin_d1 = CAMERA_PIN_Y3;
    c.pin_d2 = CAMERA_PIN_Y4;  c.pin_d3 = CAMERA_PIN_Y5;
    c.pin_d4 = CAMERA_PIN_Y6;  c.pin_d5 = CAMERA_PIN_Y7;
    c.pin_d6 = CAMERA_PIN_Y8;  c.pin_d7 = CAMERA_PIN_Y9;
    c.pin_xclk      = CAMERA_PIN_XCLK;
    c.pin_pclk      = CAMERA_PIN_PCLK;
    c.pin_vsync     = CAMERA_PIN_VSYNC;
    c.pin_href      = CAMERA_PIN_HREF;
    // Touch, PMU and the camera's SCCB all sit on GPIO 5/6. Letting the camera
    // install its own I2C driver there breaks Wire, and touch.begin() fails.
    // pin_sccb_sda = -1 makes it reuse the bus Wire already configured.
    c.pin_sccb_sda  = -1;
    c.pin_sccb_scl  = CAMERA_PIN_SIOC;
    c.sccb_i2c_port = 0;
    c.pin_pwdn      = CAMERA_PIN_PWDN;
    c.pin_reset     = CAMERA_PIN_RESET;
    c.xclk_freq_hz  = XCLK_FREQ_HZ;
    c.fb_location   = CAMERA_FB_IN_PSRAM;
    c.grab_mode     = CAMERA_GRAB_WHEN_EMPTY;
    return c;
}

// The shield mounts the OV5640 mirrored. Correct that in the sensor rather
// than with an EXIF tag, so the stored JPEG is right for any viewer and not
// just EXIF-aware ones. Everything downstream then needs no transform at all.
static void applySensorOrient()
{
    sensor_t *s = esp_camera_sensor_get();
    if (!s) return;
    s->set_hmirror(s, MOUNT_MIRROR);
    s->set_vflip(s, MOUNT_VFLIP);
}

static OV5640 af;
static bool afReady = false;

#define FW_STATUS_S_CONSTANT 0x20   // undocumented in the lib: constant AF live

// btn2 is not populated, so the panel carries the torch. Tap the viewfinder to
// shoot, tap the strip above it to toggle the fill LED.
static TouchDrvCSTXXX touch;
static bool touchReady = false;
static bool torchOn    = false;

#define STILL_W    2560
#define PREVIEW_W  320
static bool setFramesize(framesize_t fs, int wantW);

// One init for the life of the session: JPEG at the largest size we will ever
// want, so set_framesize() can move between preview and stills without losing
// exposure or the autofocus firmware.
static bool startCamera()
{
    camera_config_t c = baseConfig();
    c.pixel_format = PIXFORMAT_JPEG;
    c.frame_size   = STILL_SIZE;
    c.xclk_freq_hz = CAM_XCLK_HZ;
    c.jpeg_quality = 10;
    c.fb_count     = 1;
    if (esp_camera_init(&c) != ESP_OK) return false;

    applySensorOrient();

    sensor_t *s = esp_camera_sensor_get();
    // The AF firmware is a blob uploaded over SCCB; it survives framesize
    // changes, so this only happens here.
    afReady = af.start(s) && af.focusInit() == 0 && af.autoFocusMode() == 0;

    // Internal flash writes at ~55KB/s because NOR sector erase costs ~40ms
    // per 4KB, so on flash the file size *is* the shutter lag. Trade some
    // quality back for it; an SD card has no such problem.
    s->set_quality(s, store == &SD ? 10 : 14);

    setFramesize(PREVIEW_SIZE, PREVIEW_W);
    return true;
}

// set_framesize() takes effect a few frames later, and frames captured in the
// meantime still carry the old geometry (and can overflow the DMA buffers).
// Drain until one actually arrives at the requested width, then drop a couple
// more so exposure has caught up.
static bool setFramesize(framesize_t fs, int wantW)
{
    sensor_t *s = esp_camera_sensor_get();
    if (!s) return false;
    if (s->set_framesize(s, fs) != 0) return false;
    delay(100);

    for (int i = 0; i < 12; i++) {
        camera_fb_t *fb = esp_camera_fb_get();
        if (!fb) { delay(20); continue; }
        bool match = fb->width == wantW;
        esp_camera_fb_return(fb);
        if (match) {
            for (int j = 0; j < SETTLE_FRAMES; j++) {
                camera_fb_t *k = esp_camera_fb_get();
                if (k) esp_camera_fb_return(k);
            }
            return true;
        }
    }
    return false;
}

// --------------------------------------------------------------- storage ---

static void initStorage()
{
    // Probe SD before the display so a failed probe cannot leave the shared
    // SPI bus half-configured under TFT_eSPI. The display is on the same bus
    // and its CS is still floating at this point, so it can answer and corrupt
    // the card's replies - hold it deasserted.
    pinMode(BOARD_TFT_CS, OUTPUT);
    digitalWrite(BOARD_TFT_CS, HIGH);
    pinMode(BOARD_SD_CS, OUTPUT);
    digitalWrite(BOARD_SD_CS, HIGH);

    SPI.begin(BOARD_SPI_SCK, BOARD_SPI_MISO, BOARD_SPI_MOSI);
    // SD cards must be initialised at <=400kHz; some refuse faster probes.
    for (uint32_t hz : {20000000u, 4000000u, 1000000u, 400000u}) {
        if (SD.begin(BOARD_SD_CS, SPI, hz)) {
            store = &SD;
            storeName = "SD";
            snprintf(sdInfo, sizeof(sdInfo), "ok %luHz %lluMB",
                     (unsigned long)hz, (unsigned long long)(SD.cardSize() >> 20));
            return;
        }
        SD.end();
    }

    // Do NOT pass format_if_empty here: arduino-esp32's format path double-frees
    // (assert in multi_heap_free) and panics into a boot loop. The card must be
    // formatted FAT32 externally; exFAT, which cards ship with, is unreadable
    // by this library.
    snprintf(sdInfo, sizeof(sdInfo), "no FAT32");
    if (FFat.begin(true)) {
        store = &FFat;
        storeName = "flash";
    }
}

// Free space means little on a camera; shots taken and shots left mean a lot.
// Capacity is estimated from the average size of what has actually been
// stored, so it tracks the scene and quality setting rather than a guess.
static void scanPhotos()
{
    photoCount = 0;
    photoBytes = 0;
    if (!store) return;
    File dir = store->open("/");
    for (File f = dir.openNextFile(); f; f = dir.openNextFile()) {
        String n = f.name();
        if (n.endsWith(".JPG")) { photoCount++; photoBytes += f.size(); }
        f.close();
    }
}

static uint64_t freeBytes()
{
    if (store == &SD)  return SD.totalBytes() - SD.usedBytes();
    if (store == &FFat) return FFat.freeBytes();
    return 0;
}

// EXIF APP1 carrying nothing but an Orientation tag, so Photos rotates the
// 5MP image on display instead of us rotating 5M pixels on an ESP32.
static uint8_t EXIF_APP1[] = {
    0xFF, 0xE1, 0x00, 0x22, 'E', 'x', 'i', 'f', 0x00, 0x00,
    0x49, 0x49, 0x2A, 0x00, 0x08, 0x00, 0x00, 0x00,   // little-endian TIFF
    0x01, 0x00,                                        // 1 IFD entry
    0x12, 0x01, 0x03, 0x00, 0x01, 0x00, 0x00, 0x00,    // tag 0x0112, SHORT, 1
    0x06, 0x00, 0x00, 0x00,                            // [28] orientation value
    0x00, 0x00, 0x00, 0x00                             // no next IFD
};
#define EXIF_ORIENT_BYTE 28

static bool saveJpeg(const uint8_t *buf, size_t len, char *nameOut, size_t nameLen)
{
    uint32_t n = prefs.getUInt("n", 0) + 1;
    snprintf(nameOut, nameLen, "/IMG_%04u.JPG", n);

    File f = store->open(nameOut, FILE_WRITE);
    if (!f) return false;

    EXIF_APP1[EXIF_ORIENT_BYTE] = EXIF_ORIENT;

    bool ok = true;
    size_t off = 0;
    if (len > 2 && buf[0] == 0xFF && buf[1] == 0xD8) {
        ok &= f.write(buf, 2) == 2;                                   // SOI
        ok &= f.write(EXIF_APP1, sizeof(EXIF_APP1)) == sizeof(EXIF_APP1);
        off = 2;
    }

    // The frame lives in PSRAM, which the flash write path cannot DMA from;
    // staging through an internal-RAM buffer in sector-sized chunks is much
    // faster than handing it one large PSRAM-backed write.
    static uint8_t chunk[4096];
    while (ok && off < len) {
        size_t n = len - off;
        if (n > sizeof(chunk)) n = sizeof(chunk);
        memcpy(chunk, buf + off, n);
        ok &= f.write(chunk, n) == n;
        off += n;
    }
    f.close();

    if (ok) {
        prefs.putUInt("n", n);
        photoCount++;
        photoBytes += len;
    } else {
        store->remove(nameOut);
    }
    return ok;
}

// ---------------------------------------------------------------- capture ---

static void measureSharpness();
static bool inFocus();
extern uint16_t *decoded;

// Let a hunt finish before the shutter fires, judged on the image itself -
// the AF firmware's status register reports success unconditionally on this
// module. Never block: a scene it cannot resolve would hang the shutter.
static bool waitForFocus(uint32_t timeoutMs)
{
    uint32_t t0 = millis();
    while (millis() - t0 < timeoutMs) {
        camera_fb_t *fb = esp_camera_fb_get();
        if (!fb) { delay(20); continue; }
        bool ok = decoded && TJpgDec.drawJpg(0, 0, fb->buf, fb->len) == JDR_OK;
        esp_camera_fb_return(fb);
        if (ok) {
            measureSharpness();
            if (inFocus()) return true;
        }
    }
    return false;
}

// Switching to full res and then grabbing are the same operation: the frame
// that proves the new size took effect is itself the photo. Waiting for one
// and then fetching another costs an extra full-res readout, ~0.9s.
static camera_fb_t *grabStill()
{
    sensor_t *sn = esp_camera_sensor_get();
    if (!sn || sn->set_framesize(sn, STILL_SIZE) != 0) return nullptr;
    delay(100);
    for (int i = 0; i < 12; i++) {
        camera_fb_t *fb = esp_camera_fb_get();
        if (!fb) { delay(20); continue; }
        if (fb->width == STILL_W) return fb;
        esp_camera_fb_return(fb);
    }
    return nullptr;
}

static void capture()
{
    strcpy(status, "AF wait");
    bool locked = waitForFocus(1200);
    strcpy(status, "capturing...");


    camera_fb_t *fb = grabStill();
    if (!fb) {
        strcpy(status, "capture FAILED");
        setFramesize(PREVIEW_SIZE, PREVIEW_W);
        return;
    }

    // Copy the frame out and hand the camera back to small frames before
    // writing: at full res the sensor keeps streaming into PSRAM for the whole
    // write, and that contention dominates the shutter lag.
    size_t len = fb->len;
    uint8_t *jpg = (uint8_t *)ps_malloc(len);
    if (jpg) memcpy(jpg, fb->buf, len);
    esp_camera_fb_return(fb);

    setFramesize(PREVIEW_SIZE, PREVIEW_W);

    if (!jpg) {
        strcpy(status, "out of memory");
        return;
    }
    char name[24];
    if (saveJpeg(jpg, len, name, sizeof(name)))
        snprintf(status, sizeof(status), "%.8s %uKB%s", name + 1,
                 (unsigned)(len / 1024), locked ? "" : " ~");   // ~ = soft
    else
        strcpy(status, "write FAILED");
    free(jpg);
}

// ---------------------------------------------------------------- gallery ---
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
void loop()
{
    // ponytail: bring-up only - send '0'-'7' to try an orientation live.
    while (Serial.available()) {
        int c = Serial.read();
        if (c >= '0' && c <= '7') {
            orient = c - '0';
            updateViewfinderRect();
            snprintf(status, sizeof(status), "or%u r%d m%d e%d",
                     orient, ORI_ROT * 90, ORI_MIRROR, EXIF_ORIENT);
            Serial.println(status);
        } else if (c == 'c' && !wifiOn) {
            capture();
            Serial.println(status);
        } else if (c == 'w') {
            toggleWifi();
            Serial.printf("%s ip=%s\n", status, WiFi.softAPIP().toString().c_str());
        } else if (c == 'p') {
            // Same wire format as 'd', but the live preview frame - lets the
            // preview and the still be compared on one scene.
            camera_fb_t *fb = esp_camera_fb_get();
            if (!fb) { Serial.println("BEGIN 0\nEND"); continue; }
            Serial.printf("BEGIN %u\n", (unsigned)fb->len);   // already JPEG
            Serial.write(fb->buf, fb->len);
            esp_camera_fb_return(fb);
            Serial.println("\nEND");
        } else if (c == 'd') {
            // Raw dump of the newest JPEG: "BEGIN <size>\n", bytes, "\nEND\n".
            File dir = store->open("/");
            String last;
            for (File f = dir.openNextFile(); f; f = dir.openNextFile()) {
                String n = f.name();
                if (n.endsWith(".JPG") && n > last) last = n;
                f.close();
            }
            if (!last.startsWith("/")) last = "/" + last;
            File f = store->open(last);
            if (!f) { Serial.println("BEGIN 0\nEND"); continue; }
            Serial.printf("BEGIN %u\n", (unsigned)f.size());
            uint8_t chunk[512];
            while (f.available()) Serial.write(chunk, f.read(chunk, sizeof(chunk)));
            f.close();
            Serial.println("\nEND");
        } else if (c == 'i') {
            Serial.printf("storage=%s free=%llu autofocus=%d touch=%d wifi=%d torch=%d "
                          "reset=%d heap=%u psram=%u batt=%umV(%s) chg=%d ichg=%umA ilim=%umA "
                          "sd[%s] sharp=%u peak=%u foc=%d\n",
                          storeName, (unsigned long long)freeBytes(), afReady, touchReady,
                          wifiOn, torchOn, (int)esp_reset_reason(),
                          (unsigned)ESP.getFreeHeap(), (unsigned)ESP.getFreePsram(),
                          (unsigned)battMv, battPctStr(), PMU.isCharging(),
                          (unsigned)PMU.getChargerConstantCurr(),
                          (unsigned)PMU.getInputCurrentLimit(), sdInfo,
                          (unsigned)sharpness, (unsigned)sharpPeak, inFocus());
        } else if (c == 'l') {
            File dir = store->open("/");
            for (File f = dir.openNextFile(); f; f = dir.openNextFile()) {
                Serial.printf("  %s %u\n", f.name(), (unsigned)f.size());
                f.close();
            }
            Serial.printf("free=%u\n", (unsigned)freeBytes());
        }
    }

    // Shutter is btn3, not btn1: btn1 is GPIO0, the BOOT pin, so any reset
    // while it is held brings the board up in ROM download mode - a blank
    // screen that only a power cycle clears. Keeping the most-pressed button
    // off GPIO0 makes a reset merely a reset. It also puts the shutter on the
    // right, which is where a right hand wants it.
    bool p1 = pressed(0), p3 = pressed(16);
    if (wifiOn) {
        if (p1 || p3) toggleWifi();     // both labels read BACK
    } else {
        if (p3) capture();
        if (p1) toggleWifi();
    }

    int tx, ty;
    if (touchTap(tx, ty) && !wifiOn) {
        if (ty >= vfY && ty < vfY + vfH) capture();          // viewfinder
        else if (ty < vfY)               setTorch(!torchOn); // strip above it
    }

    if (wifiOn) { dns.processNextRequest(); server.handleClient(); }
    else      { drawViewfinder(); measureSharpness(); }

    pollBattery();
    drawStatus();
}

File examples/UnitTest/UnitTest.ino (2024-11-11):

/**
 * @file      UnitTest.ino
 * @author    Lewis He (lewishe@outlook.com)
 * @license   MIT
 * @copyright Copyright (c) 2023  Shenzhen Xin Yuan Electronic Technology Co., Ltd
 * @date      2023-09-14
 * @note      T-Display-Pro Factory test example
 *
 * *       Arduino Setting
 *            Tools ->
 *                  Board:"ESP32S3 Dev Module"
 *                  USB CDC On Boot:"Enable"
 *                  USB DFU On Boot:"Disable"
 *                  Flash Size : "16MB(128Mb)"
 *                  Flash Mode"QIO 80MHz
 *                  Partition Scheme:"16M Flash(3M APP/9.9MB FATFS)"
 *                  PSRAM:"OPI PSRAM"
 *                  Upload Mode:"UART0/Hardware CDC"
 *                  USB Mode:"Hardware CDC and JTAG"
 *  Arduino IDE User need move all folders in [lib folder](./lib/)  to Arduino library folder
 */

#include <Wire.h>
#include <SPI.h>
#include <Arduino.h>
#include <TouchDrvCSTXXX.hpp>
#include <SensorLTR553.hpp>
#include <XPowersLib.h>
#include <TFT_eSPI.h>
#include <lvgl.h>
#include "utilities.h"
#include "freertos/semphr.h"
#include <SD.h>
#include <WiFi.h>
#include <esp_wifi.h>
#include <esp_camera.h>
#include <HTTPClient.h>
#include <WiFiClientSecure.h>
#include "rootCa.h"
#include "zones.h"
#include "img_converters.h"
#include <AceButton.h>
//QWIIC MPU9250 DEPENDENT
#include <MPU9250.h>
//QWIIC MPU6050 DEPENDENT
#include <I2Cdev.h>
#include <MPU6050.h>
// Optional 6-axis sensor module
#include <SensorBHI260AP.hpp>
#include <MadgwickAHRS.h>       //MadgwickAHRS from https://github.com/arduino-libraries/MadgwickAHRS

using namespace ace_button;

#ifndef WIFI_SSID
#define WIFI_SSID           "Your WiFi SSID"
#endif

#ifndef WIFI_PASSWORD
#define WIFI_PASSWORD       "Your WiFi PASSWORD"
#endif

#define NTP_SERVER1           "pool.ntp.org"
#define NTP_SERVER2           "time.nist.gov"
#define GMT_OFFSET_SEC        0
#define DAY_LIGHT_OFFSET_SEC  0
#define GET_TIMEZONE_API      "https://ipapi.co/timezone/"
#define DEFAULT_TIMEZONE      "CST-8"         //When the time zone cannot be obtained, the default time zone is used


#define SPI_LOCK            xSemaphoreTake(spiLock,portMAX_DELAY)
#define SPI_UNLOCK          xSemaphoreGive(spiLock)
#define UI_BG_COLOR         lv_color_make(241, 150, 23)
#define UI_FRAME_COLOR      lv_color_make(255, 255, 255)
#define UI_FONT_COLOR       lv_color_make(65, 65, 64)


LV_FONT_DECLARE(font_ali);


TFT_eSPI tft = TFT_eSPI();
TouchDrvCSTXXX touch;
PowersSY6970 PMU;
SensorLTR553 als;
WiFiClientSecure client;
HTTPClient https;
String httpBody;
AceButton buttons[BOARD_USER_BTN_NUM];
uint8_t buttonsArray[BOARD_USER_BTN_NUM] = BOARD_USER_BUTTON;
// MPU9250/MPU6050 non onboard sensors, default access from QWIIC interface
MPU9250 mpu;
MPU6050 accelgyro;

#include <cbuf.h>
//BHI260AP Optional 6-axis sensor module
SensorBHI260AP bhy;
void gyro_process_callback(uint8_t sensor_id, uint8_t *data_ptr, uint32_t len, uint64_t *timestamp);
void accel_process_callback(uint8_t sensor_id, uint8_t *data_ptr, uint32_t len, uint64_t *timestamp);
cbuf accel_data_buffer(10);
cbuf gyro_data_buffer(10);
Madgwick filter;

static int16_t x[5], y[5];
static bool hasPMU, hasALS, hasTouch, hasCamera, hasMPU9250, hasMPU6050, hasSD, hasBHI260;
static bool isBacklightOn = true;
static bool manualOff = false;
static SemaphoreHandle_t spiLock;
static TaskHandle_t  vUpdateDateTimeTaskHandler = NULL;
static camera_sensor_info_t *sinfo = NULL;

#define CANVAS_WIDTH        480
#define CANVAS_HEIGHT       222
#define CANVAS_FORMART      LV_IMG_CF_TRUE_COLOR  // = RGB565

static lv_obj_t *canvas;
static lv_color_t *colorBuffer;
static lv_obj_t *hour_text;
static lv_obj_t *min_text;
static lv_obj_t *als_label ;
static uint8_t pageId = 0;
static bool cameraRun = false;
static bool sdRun = false;
static bool capture = false;
static lv_obj_t  *massStorageList;
static camera_config_t cameraConfig;
static bool ir_state = 1, led_state = 1;
static lv_obj_t *imageView = NULL;
static lv_obj_t *labelPoint = NULL;
static const char *format_string = "#FFFFFF X:%d# #FFFFFF Y:%d#\n ";

void initButton();
void lv_helper();
void clockUI(lv_obj_t *parent);
void initBackLight();
bool initPMU();
bool initCapacitiveTouch();
bool initSensor();
void setBrightness(uint8_t bri);
bool initSD();
bool initCamera();
void initWiFi();
void initGUI();
void massStorageUI(lv_obj_t *parent);
void datetimeSyncTask(void *ptr);
void cameraUi(lv_obj_t *parent);
void listDir(fs::FS &fs, const char *dirname, uint8_t levels);
void handleEvent(AceButton *button, uint8_t eventType, uint8_t buttonState);
void buttonHandler(void *);
void massStorageEventHandler(lv_event_t *e);
void saveJPEG(camera_fb_t *fb);



void boundariesUI(lv_obj_t *parent)
{
    labelPoint = lv_label_create(parent);
    lv_label_set_long_mode(labelPoint, LV_LABEL_LONG_WRAP);     /*Break the long lines*/
    lv_label_set_recolor(labelPoint, true);                      /*Enable re-coloring by commands in the text*/
    lv_obj_set_width(labelPoint, 150);  /*Set smaller width to make the lines wrap*/
    lv_obj_set_style_text_font(labelPoint, &lv_font_montserrat_28, LV_PART_MAIN);
    lv_obj_set_style_text_align(labelPoint, LV_TEXT_ALIGN_CENTER, 0);
    lv_obj_align(labelPoint, LV_ALIGN_CENTER, 0, 0);

    lv_align_t  align[] = {LV_ALIGN_TOP_LEFT,
                           LV_ALIGN_TOP_MID,
                           LV_ALIGN_TOP_RIGHT,
                           LV_ALIGN_BOTTOM_LEFT,
                           LV_ALIGN_BOTTOM_MID,
                           LV_ALIGN_BOTTOM_RIGHT,
                           LV_ALIGN_LEFT_MID,
                           LV_ALIGN_RIGHT_MID
                          };
    for (int i = 0; i < sizeof(align) / sizeof(*align); ++i) {
        lv_obj_t *btn = lv_btn_create(parent);
        lv_obj_set_size(btn, 60, 60);
        lv_obj_t *label = lv_label_create(btn);
        lv_label_set_text_fmt(label, "%d", i);
        lv_obj_add_flag(btn, LV_OBJ_FLAG_CHECKABLE);
        lv_obj_center(btn);
        lv_obj_align(btn, align[i], 0, 0);
    }
}

void serialToScreen(lv_obj_t *parent, String string,  bool result)
{
    lv_obj_t *cont = lv_obj_create(parent);
    lv_obj_set_scroll_dir(cont, LV_DIR_NONE);
    lv_obj_set_size(cont, LV_PCT(100), lv_font_get_line_height(&lv_font_montserrat_28) + 2 );

    lv_obj_t *label1 = lv_label_create(cont);
    lv_label_set_recolor(label1, true);
    lv_label_set_text(label1, string.c_str());
    lv_obj_align(label1, LV_ALIGN_LEFT_MID, 0, 0);

    lv_obj_t *label = lv_label_create(cont);
    lv_label_set_recolor(label, true);
    lv_label_set_text(label, result ? "#FFFFFF [# #00ff00 PASS# #FFFFFF ]#" : "#FFFFFF [# #ff0000  FAIL# #FFFFFF ]#");
    lv_obj_align(label, LV_ALIGN_RIGHT_MID, 0, 0);

    lv_obj_scroll_to_y(parent, lv_disp_get_ver_res(NULL), LV_ANIM_ON);

    int i = 200;
    while (i--) {
        lv_task_handler();
        delay(1);
    }
}
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

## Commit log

2023-09-25 Update board ini
2023-09-25 Update Board config
2023-09-25 Added CapacitiveTouch example
2023-09-25 Added Sensor example
2023-09-25 Added camera example
2023-09-25 Added Arduino_GFX_LvglBenchmark example
2023-09-25 Update schematic
2023-11-23 Add Vice-Shield Gerber & dxf
    [T-Display-Pro-Vice-Shield.dxf]
2023-12-01 Add DWG
    [T-Display-Pro-PCB.DWG]
2023-12-12 fix GC0308 frame reversal problem，
    [Cellphone.ino, sd_card.cpp, ui.cpp]
2023-12-18 Add vibrating motor demo
    [Cellphone.ino, ui.cpp, utilities.h]
2023-12-27 Add 9-axis sensor demo (Model :ICM20948)
2024-01-03 Update Arduino IDE steps
2024-01-03 Fixed ArduinoIDE compile
2024-01-03 Add ICM20948 lib and fix compilation errors in Arduion
    [ui.cpp]
2024-01-19 Add buttons to control lens rotation
2024-01-19 Set the default project to “example/factory”
2024-02-01 Added BackCover by @moononournation
    [K231-camera-back v6.f3d, K231-lens-mount v3.f3d]
2024-02-26 Solve the problem that the color of the picture is abnormal when the camera is saved to the SD card
    [sd_card.cpp]
2024-04-30 Add touch boundary test https://github.com/Xinyuan-LilyGO/T-Display-S3-Pro/issues/4
    [UnitTest.ino]
2024-11-09 Modify the schematic of T-Display-S3-Pro-MVSRBoard
2024-11-11 Remove touch pin error definition
    [utilities.h]
2024-11-11 Update SensorLib to v0.2.2
2024-11-11 Update SensorLib touch initialization
2025-01-15 Added GFX Library for Arduino 1.3.7
2025-01-15 GFX Library for Arduino Fixed version 1.3.7 ,Fixed CI
2025-01-16 Added display SD picture https://github.com/Xinyuan-LilyGO/T-Display-S3-Pro/issues/19
    [TJpg_Decoder.ino, utilities.h]
2025-08-25 Update Arduino_DriveBus version to v1.1.16
2025-11-03 Added sensor kmod ,sch https://github.com/Xinyuan-LilyGO/T-Display-S3-Pro/issues/25
2026-08-04 Add PointShoot example: standalone camera with WiFi photo transfer
    Turns the T-Display-S3-Pro plus camera shield into a self-contained
    point-and-shoot: live viewfinder, full-res stills to storage, and a WiFi
    AP serving a gallery so photos can be pulled onto a phone with no app or
    cable. btn3 shoots, btn1 toggles the AP, and the touch panel gives a
    tap-to-shoot viewfinder and a torch toggle.
    Four things were measured on hardware rather than assumed, and the
    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
    [partitions_camera.csv]
2026-08-04 PointShoot: battery state of charge indicator
    Shows remaining charge in the top-right of the status bar, coloured
    green above 40%, yellow to 15%, red below.
    The SY6970 has no fuel gauge, so charge is inferred from battery voltage
    against a LiPo discharge curve. Two things that measurement has to
    account for:
    - While charging, the terminal voltage is held up by the charger and is
    not the cell's resting voltage. Converting it reads ~98% whatever the
    real charge, so no percentage is shown on USB - the field reads "USB"
    instead, and the curve is only applied while discharging.
    - The smoothing history is discarded when the charge state flips, so the
    first reading after unplugging is th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
    [PointShoot.ino]
2026-08-04 PointShoot: show shots taken and shots remaining
    Replaces free megabytes in the status bar with a photo count and an
    estimated capacity, which is what actually matters when shooting.
    The remaining count is derived from the mean size of the photos already
    stored rather than a fixed assumption, so it follows the quality setting
    and the scene: detailed frames compress worse and eat the estimate
    faster. It re-averages on every shot, so it self-corrects instead of
    accumulating error.
    The count is updated incrementally when a photo is written, avoiding a
    directory scan per shot, and rescanned after a delete from the gallery
    so the two cannot drift apart.
    Also drops the reset-cause banner from t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
    [PointShoot.ino]
2026-08-04 PointShoot: SD storage, faster shutter, bulk delete, captive portal
    Shutter drops from ~9s to ~1.8s, measured per phase on hardware:
    write 5-7s -> 0.25s an SD card has no NOR sector erase; internal
    flash managed ~55KB/s, the card does ~1.2MB/s
    size 3.4s -> 0.5s SETTLE_FRAMES 2 -> 0, and the frame that proves
    set_framesize() took effect is now used as the
    photo instead of being discarded and another
    full-res frame fetched
    total ~9s -> ~1.8s
    Dropping the settle frames is safe because exposure no longer restarts
    per shot - that requirement disappeared when the per-shot deinit/in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
    [PointShoot.ino]
